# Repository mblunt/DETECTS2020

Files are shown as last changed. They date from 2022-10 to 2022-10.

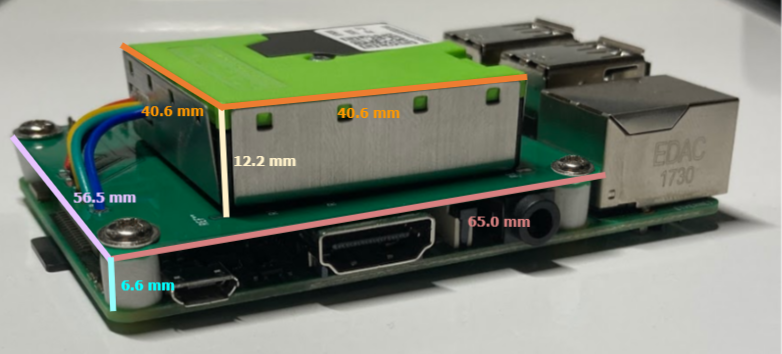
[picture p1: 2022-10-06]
Pictures/Experiment.PNG

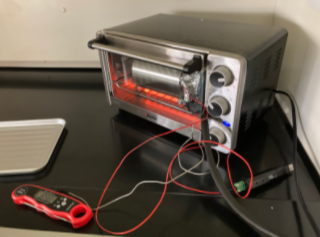
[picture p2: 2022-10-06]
Pictures/HeatTest.PNG

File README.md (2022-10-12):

# Experiment Test Report
### Update
##### Project accepted on AR2B, experiment will be traveling to the International Space Station. For any questions, please contact this experiment's Project Manager, Michael Blunt at michaelbblunt@gmail.com.

### 1.0	Introduction
“Smells Like Particulate Matter” is Palmetto Scholars Academy’s team in the Data Evaluation From Testing via an Educational Challenge with Teachers and Students (DETECTS) initiative with the University of Alabama in Huntsville (UAH). The DETECTS mission will take place in ACES RED 2B (AR2B) on an external pallet attached to the International Space Station (ISS). AR2B’s primary objective is to study quantum entanglement technology in space satellite communications. The primary purpose of DETECTS on AR2B is to investigate the use of low-cost commercial-off-the-shelf (COTS) hardware. The team’s mission is to develop an experiment that utilizes a Raspberry Pi computer in conjunction with sensors to fulfill a scientific objective. The team must select a scientific objective to build an experiment around, program the Pi, and confirm that it meets all functional and environmental requirements through testing. In addition, they must professionally communicate their progress with a panel of evaluators. 
All DETECTS teams were given a detailed Request for Experiment (RFE) and Interface Control Document (ICD) with the requirements that must be met in order to qualify for a slot on AR2B. The experiment would be stored in AR2B, where it would generate and relay data back to the team for evaluation. The project requirements for the team’s experiment is broken down into four categories. The team must follow mechanical and spatial requirements by keeping the experiment no larger than 65 mm by 56.5 mm by 19 mm, and by not modifying the existing Pi mounting configuration or the existing 40W connector pins. Electrical requirements detail that the experiment must be compatible with the existing 40W pinout and that the team cannot use pins 30 or 31. Mechanical aspects of the experiment must be stationary and solid to avoid any damage to the experiment and AR2B. The team cannot include: liquids or gasses of any kind, organic material, loose or powdered material, high voltage equipment (>28V), EMF producing equipment, pressurized vessels, moving parts, reconfigured pinouts, fracturing or shattering materials, batteries, or electrolytic capacitors. In terms of software, all programs must be able to interface and collect data from a Pi HAT and not exceed a data rate of 5 kilobytes per second (kBps). Also, the team must be able to communicate with the AR2B flight computer via the team’s unique JSON packets passed to UAH’s team sender program through placement in the /tmp/experiment directory.

### 2.0	Science Objective and Instrumentation
The team came up with a total of three potential science objectives, “Material Reflectivity,” “Commercial Grade Contaminants Comparison,” and “Fiber Optic Radioactivity.” Material Reflectivity would measure the reflectivity of specific materials with a reflectance sensor within the near-zero lux environment of the AR2B tray. Many consumer technology devices, such as screens, use reflectivity to function, so specific research on reflectivity can assist in material selection for future spaceflight missions. Commercial Grade Contaminants Comparison would be studying and assessing the particulate matter present on AR2B utilizing a particulate matter sensor. There is a significant price difference between consumer and professional grade particulate sensors, and analyzing a consumer grade sensor will establish whether or not this differential is warranted. Fiber Optic Radioactivity would study the effects of background radiation on fiber optic cabling by utilizing a simple voltage output and input to measure any losses. This is key to figuring out the effects of spatial radiation on connectivity with fiber optics. 
In order to choose a scientific objective to pursue, the team used a science objective trade study (Table 2) with weighted figures of merit (FOMs). The FOMs assigned by UAH were Interest of Team, Measurement Method, Likelihood of Success, Sensor Complexity, Sensor Resolution, and Scientific Ramifications. In addition, the team added three FOMs: Justifiability, Public Interest, and Public Comprehension. All FOMs were given a weight of either 1, 3, or 9. After careful consideration and research, “Commercial Grade Contaminants Comparison” won with a weighted score of 337, due to its high scores in Measurement Method, Likelihood of Success, and Interest of Team. The high score in Measurement Method was due to the highly tested nature and quality of the instrument, and high scores in likelihood of success are due to the stability of the experiment’s design in concept and programming.
“Commercial Grade Contaminants Comparison” will establish an experiment to compare the quality and quantity of data collected by commercial-grade vs professional-grade equipment. In order to do this, the team will assess particulate density, prevalence, size, and levels over time while onboard AR2B in order to proceed with a data comparison analysis. All of this will be done in order to gather data on the difference in both the quality and quantity of measurements between consumer and professional-grade sensor technology. After some research on different types of sensing technology, the team has come to believe that the inaccuracy of data generated by commercial-grade sensing technology will not be impressive enough to warrant the costs typically associated with the more expensive professional equipment. The goal in mind for this experiment is to determine whether or not commercial-grade sensors and COTS (Commercial Off the Shelf) hardware are accurate and reliable enough to be used in future missions. If the data gathered from the prospective experiment provides evidence in support of this claim, COTS equipment may be able to replace or supplement far more expensive sensors that have similar purposes. In order to complete the science objective, the experiment must be able to measure particulate density, prevalence, size, and levels over time. Also, the sensor must be able to take measurements on AR2B. 
After significant research, the team decided on the Sensirion Particulate Sensor 30 (SPS30), a consumer-grade particulate matter sensor (See Science traceability Matrix, Table 1). The SPS30 features a compact design, measuring 40.6 mm x 40.6 mm x 12.2 mm, and can measure particulate matter as small as 0.3 μm, a figure slightly better than the posted value for the ISS’s Analysing Interferometer for Ambient Air (ANITA), which currently serves as the ISS’s air quality monitoring system. The SPS30 also features an impressive accuracy of +/-10 μg/m3, as well as a long term accuracy drift of +/- 1.25 μg/m3 per year and a Pi compatible digital output. The SPS30’s small profile combined with very high accuracy and reliability ultimately made it the best fit for the team’s experiment. Due to the design of the SPS30 and the microgravity conditions the experiment will experience, the experiment will be able to take highly accurate measurements simply by running and has no notable limiting requirements. In Table 2, the team describes the process through which the team used to determine the best sensor for their science objective.
The reason the team chose to research a particulate matter sensor, in particular, is based on research the team has done into the ISS’s current air quality monitoring system, the aforementioned ANITA. It is a system that can measure particulate matter up to the “high parts per billion” or >0.5 μm range, as well as to detect over 32 different types of harmful trace gasses. It was developed in the early 2000s, and presumably cost multiple millions of dollars to produce, engineer, design, and qualify. This team’s experiment includes a $45 sensor that can detect smaller particles (>0.3 μm) with a higher degree of accuracy. This team believes that the current particulate matter sensors used in spaceflight missions may be outdated; in addition, the laser-based measurement technology as seen in sensors like the SPS30 may prove to be better suited for missions than the infrared technology used in older sensors such as the one integrated into ANITA. This team believes that an SPS30 may be able to produce results with comparable or higher accuracy to the existing ANITA system, with the added perk of a price point less than 0.001% of the cost of the existing technology (assuming the particulate sensor in ANITA cost at least 5 million to develop, engineer, and implement). With this stated, the team is by no means questioning the accuracy or engineering of the ANITA, as sensing particulate matter is just one of many functions it performs. The above explanation of the ANITA is by no means all-encompassing, and a device like SPS30 could never replace such a system by itself; However, validating the accuracy and usability of a COTS device such as the SPS30 aligns very well with the secondary objective of AR2B, could potentially have very important implications in terms of future mission costs, and could also lead to new, more accurate systems being created with these new technologies. 

#### Table 1. Science Traceability Matrix

Table_1

#### Table 2. Science Objective Trade Study

table_2

### 3.0 Configuration
The team’s mission utilizes an SPS30 mounted on a custom Raspberry Pi Hardware Attached on Top (HAT). The HAT is a printed circuit board (PCB) with dimensions of 65 x 56.5 x 0.8 mm. This HAT integrates the selected sensor, the SPS30, by mounting it via screws and a connector for the sensor. This allows for a stable mount throughout the course of the mission. The HAT design also allows for the use of the 5 pin connector standard utilized by the SPS30 for ease of installation and troubleshooting. Additionally, the HAT meets all the requirements for a Pi HAT, such as utilizing all 40 general-purpose input/output (GPIO) pins and following all solder trace placement guidelines. The HAT is mounted utilizing 6mm standoffs, to ensure the most stability when AR2B encounters inclement conditions. As depicted in Figures 1, 2, and 3, the SPS30 will be roughly centered on the Pi HAT and will be connected to the GPIO pins via the traces and solder connection pads integrated into the PCB board.

#### Figure 1. HAT CAD



#### Figure 2. 3D CAD



#### Figure 3. CAD Side View



#### Figure 4. Concept of Operations Flowchart



### 4.0	Concept of Operations
This experiment divides its concept of operations into three phases. Phase 1 is dedicated to powering up and utilizes a cron job to launch all of the required programs. During this phase, the SPS30 also powers on, and the monitor program ensures that all programs launched successfully. During Phase 2, the experiment operates for twelve hours at a time, then stops and restarts for approximately two minutes. This restart period ensures that if any errors are missed by the monitor program during the mission, a minimal amount of data would be lost. Additionally, the monitoring program performs a soft restart (SPS30 power is not cut) if an error occurs. During this phase, the experiment sends data to the AR2B data handling system at a max data rate of 0.5 kilobytes per second. During Phase 3, the experiment sends its last data packet and powers off approximately 14 days before the end date of AR2B. This is to ensure that little data is lost, while also ensuring that the team does not interfere with AR2B’s end of life plans. After the team receives all the data from the experiment, the team will look for any statistically significant data present, and then create a report outlining the findings, and the implications thereof. This team’s concept of operations is depicted visually in Figure 4.

### 5.0	Programming
The team’s mission program consists of five crucial programs: A startup program, a sensor program, a transfer program, a monitor program, and UAH’s program. Figure 5 shows the basic operation of the programs. In Figure 5, the team uses green lines to represent the data cycle of the program, red lines to represent a triggered restart, and the blue lines represent the log cycle. 
The startup program is launched as part of the Pi’s bootup sequence through a feature built into the native Linux-based operating system called a cron job. This cron job runs automatically as part of the Pi bootup sequence and launches the startup program. Then, the startup program initializes and launches all of the programs needed for the mission, as well as starting a twelve-hour restart timer. The startup program is written in Bash due to Bash’s compatibility with the native Linux-based shell. The startup program launches the monitor program two minutes after the Pi’s bootup sequence completes. This allows time for all of the other programs to launch and begin functioning properly. After the two minutes are elapsed, the monitor program checks to make sure that all other programs are running. If a program has terminated or stopped producing data, the monitor program will initiate a soft system restart. The monitor program is written in Python. 
The startup program also launches the sensor program (immediately). The sensor program, written in Python, configures the sensor by writing to the sensor’s control registers and reading data from the sensor’s output registers. This data is collected by the Pi by the I2C protocol and is packaged into a timestamped JSON file no more than sixty times per minute. Because the largest possible data packet is approximately 450 bytes, the maximum data rate of the experiment is 0.5 kBps. The data output from the sensor can delineate by particulate matter diameter (<0.5μg, <1μg, <4μg, <10μg, >10μg) and also calculates particulate matter density in μg/m3. All of this data is very useful for validating the accuracy and reliability of the SPS30. Specifically, this gathered data will be analyzed by the team and compared to predicted results, testing results, prior mission results, and any other data figures relevant to the collected data. Depicted in Figure 6 is a screenshot of a JSON data packet assembled by the sensor program. 
The transfer program is a simple program designed to move the timestamped JSON files to the /tmp/experiment/ directory (folder) as required by the DETECTS ICD. All this program does is make the /tmp/experiment/ directory, as it is intentionally deleted by the system with every reboot, and it moves all JSON files to the /tmp/experiment/ directory to be handled by UAH’s program. The transfer program is written in Bash.
### 6.0 Functional and Environmental Requirements
While onboard AR2B, the experiment will have to remain functional within the environment. As defined by the RFE and ICD, there are certain functional requirements alongside several environmental requirements that must be met in order to qualify as a sub experiment for AR2B.
In order to meet the basic functional requirements laid out by the RFE and ICD, the experiment must be able to take measurements, organize data packets, and send data. This team chose to include several more requirements to better suit the mission and demonstrate the team’s focus on safety and reliability. These additional requirements include establishing an accurate particulate count, handling program errors, and resuming operation after a reboot. The latter two requirements were added in order to take into account unpredictable or unexpected errors that may occur during the mission. 
To be able to meet the environmental requirements, the experiment must survive the conditions that will be experienced while aboard AR2B. These environmental conditions include surviving extreme temperatures (as low as -20℃ and up to 90℃), surviving a vacuum, and surviving up to 4 gs of random vibration. 

#### Figure 5. Program Flowchart



#### Figure 6. Example Data Packet



### 7.0	Testing
In order to meet the functional and environmental requirements required by the team and UAH, the team created a test plan for functional and environmental testing. The tests designed include the functional tests, which includes the Sensor, Transfer, and Recovery, as well as the environmental tests, which include the Vacuum, Thermal, and Vibration tests. For all of these tests, the safety of the team members and the experiment was considered to be the main priority. During testing, team members present wore proper personal protective equipment (PPE), had emergency equipment in the room, cleaned and inspected all equipment before use, and made sure they were operating in a clear and safe lab environment. Steps taken to ensure the safety of the experiment include using grounded wristbands and ground-fault circuit interrupter (GFCI) equipped outlets. In addition to the listed precautions, additional measures were taken for certain tests due to a unique situation posed by the test or testing environment.
The first functional test, the Sensor test, was created to determine if the experiment can take measurements, organize data packets, send data, and establish an accurate particulate count. For the experiment to pass this test, it must accurately reflect an increase in particles when a particulate source is introduced. For this test, the experiment was placed in an enclosed container and was run for one hour to establish a baseline measurement. Then, a lit butane lighter was inserted into the container for 5 seconds. Following this, the testers removed the lighter and resealed the container. The test was successful as the experiment worked as expected, showing a 17,600% increase in particulates (μg/m3). 
The Transfer Test was the team’s second functional test, and it was made to determine if the experiment can organize data packets and send data. To pass this test, the experiment must accurately transfer JSON data packets from the /tmp/experiment/ directory to the UAH transfer program. This test was completed by simply powering on the experiment, and ensuring that the UAH program was receiving the packets via the program’s built-in data rate feature. The transfer program was successful in transferring the time-stamped files to the /tmp/experiment/ directory, and per the UAH transfer program, the experiment has a current maximum data rate of 0.5 kBps and an average of 0.3kBps. This test was run 25 times with zero failures.
The final functional test was the Recovery Test, which determined if the experiment can handle program errors and resume operation after a reboot. To pass this test, the experiment must be able to restart after SPS30 power loss, disconnected GPIO wires, and halted programs. The test was run 50 times with the experiment rebooting successfully every time. 
The Thermal Tests, namely the cold and heat test, were completed in order to meet the requirements of surviving within the temperature extremes of -20℃ and 90℃. To pass these tests, the experiment had to be able to function and take measurements while experiencing temperatures up to 90℃ and as low as -20℃. This test was completed using a freezer cooled to -20℃ (pictured Figure 7) and a toaster oven provided by UAH (pictured Figure 8), which was heated to 90℃. First, each individual component of the experiment, the PCB, SPS30, and wires, were each tested at 90℃ for an hour and -20℃ for an hour. After testing the individual parts of the experiment, the fully assembled configuration was operated at 90℃ for one hour and -20℃ for one hour. During each environmental condition, a variation of the sensor test was completed to demonstrate the experiment’s ability to function at different temperatures. This variant of the sensor test was completed by inserting the experiment into a particulate containing canister. During the cold test, this variant of the sensor test was completed for 10 minutes in the middle of the cold test, creating a 0-25 minute cold test and a 35-60 minute cold test. The experiment worked as expected and the sensor was able to function successfully in both environments.
 The vacuum test was made to determine if the experiment could survive, take measurements, organize data packets, and send data in vacuum-like conditions. To pass the vacuum test, the experiment was required to be able to survive (UAH requirement) and operate (Team Requirement) within a vacuum for 30 minutes. Prior to testing, a vacuum chamber provided by UAH was cleaned, re-oiled, and inspected for defects. After this, the experiment was run inside the vacuum chamber for 30 minutes (pictured Figure 9). While re-pressurizing the chamber, we introduced particulates to further demonstrate the experiment’s ability to function in a vacuum. The experiment was able to survive and detect particulates while operating within a vacuum for 30 minutes and met all requirements set by the team and UAH; therefore, the experiment passed the vacuum test. 

#### Figure 7. Cold Testing Setup



#### Figure 8. Heat Testing Setup



#### Figure 9. Vacuum Test Setup



The random vibration test was designed to determine if the experiment could maintain structural integrity while experiencing up to 4g of random vibration (max g-forces shown in Table 3). The purpose of this test is to simulate rocket launch. To pass this test, the experiment must remain intact and operable after surviving these conditions. For this test, the payload and a UAH provided accelerometer was secured to a baseplate (experiment depicted in Figure 10) and vibrations were introduced for 15 minutes according to UAH recommended testing guidelines. Specifically, the experiment and accelerometer were mounted to a wooden board and placed on an egg crate foam dampener. Then, the board was hit at different angles with a rubber mallet into the egg crate foam dampener to generate the necessary g load without putting undue stress on the experiment. After testing, the experiment was inspected for any hanging or disheveled parts and the data collected afterwards was compared to the data collected prior to testing to determine success or failure. Ultimately, the experiment passed the vibration test as the experiment was able to survive and function accurately after the vibration test.

#### Figure 10. Securely Mounted Pi



#### Table 3. Calculated G-Forces on Pi

table_3

### 8.0	Data Analysis
 The team was careful to take a sequential and organized approach to gathering and analyzing data. After a test was conducted, all data packets gathered during the test were transferred to an analysis computer via a remote connection. Once the data was successfully transferred to the analysis computer, a Python program designed to extract relevant data was run on the collected data packets. Once the necessary data had been extracted, the data points were imported into a labeled spreadsheet. Once in the spreadsheet, that data was analyzed using a variety of statistical tools, formulas, and graphs. The team conducted many types of regression, created control charts, estimated confidence intervals, f-tests, and many other types of analyses. 
 As suggested by UAH presentation guidelines, the team conducted a statistical analysis on data collected during the functional tests. For the recovery and transfer test, no new information could be gathered by analyzing the particulate data collected, as the manipulated variable for those tests was independent of all variables affecting the reliability of the SPS30 itself. For the Recovery test, no notable data could be gathered except that the triggered error to shutdown delay time is less than one second, and the reboot time is a maximum of 120 seconds. For the transfer test, the largest possible data packet was approximately 0.47 kilobytes, and at a set maximum rate of 1 data packet per second, the maximum possible data rate is 0.47 kBps based on the data from the transfer test. To determine the average data rate, the total size of 600 data packets was divided by the total time taken to transfer the packets, resulting in an average data rate of 0.312 kBps. For the sensor test, a baseline sample was taken for 1 hour. As the baseline particulate count was so small compared to the values collected after particulates were introduced (a ratio of 1:178), there was no need to conduct an analysis to see if there was a difference in particulates between the baseline and testing data. As opposed to the limited analysis conducted for the functional tests, the team decided to conduct a much deeper analysis of the data gathered during environmental tests that was required by UAH.
 For the environmental tests (vacuum, thermal, and vibration tests) UAH only required a basic analysis of the data collected. The suggested method for data analysis was to visually compare collected data to a baseline. This team decided to conduct deeper analysis to validate the functionality of our sensor in addition to comparing data to a baseline as recommended by UAH. For the thermal (heat and cold) tests as well as the vacuum tests, the same statistical process was used to analyze the data. This process was (in essence) to take the derivative of the particulate data and create a linear regression (a linear line of best fit) from this data. The purpose of taking the derivative of all of the particulate data was to determine if the rate of change of the data over time was increasing, decreasing, or remaining constant. 
When the graph of the thermal (heat and cold) tests were analyzed, the team discovered that the slope of the linear regression of the data was slightly negative for both tests (shown in Figure 12), indicating that the total number of particles had decreased during the test. However, this decrease was so small, that, when applied back to the original data set, it resulted in a decrease of approximately 6.733 ng/m3 (heat test) and 17.823 ng/m3 (cold test 0-25) and 12.909 ng/m3 (cold test 35-60). After determining this, the team realized that the decrease was so small that it could be considered an insignificant data point. Furthermore, the environment could not be fully controlled, due to the location of the heat test in a fume hood and unsealed oven, and the cold test in a partially sealed container and a standard freezer. As such, slight inconsistencies are to be expected and, due to the nature of the experiment, are irrelevant to the team’s objective. 
When the data from the vacuum test was analyzed, the team discovered that the slope of the linear regression of the data was exactly zero (shown in Figure 11). Using this statistical evidence, the team concluded that regardless of fluctuations, the amount of particulates within the vacuum chamber remained constant. This data supports the hypothesis of the team, who inferred that because the vacuum chamber is a sealed container with no particulate sources, the particulates count within the container will remain constant. This statistical analysis, in addition to the baseline, effectively demonstrated the experiments ability to survive, collect data, send data, and function accurately within a vacuum.

#### Figure 11. Vacuum Test Data Analysis



#### Figure 12. Heat Test Data Analysis



Finally for the vibration test, no particulate data was collected, as the experiment will not be operating in an environment that this test attempts to simulate, namely, the rocket launch. However, before and immediately after the vibration test (Figures 13 and 14), the experiment was powered on to verify that the sensor and all connections were working properly and establish baselines. From both baselines, 600 data packets were gathered and compared. Both baselines had their upper limits within ± 0.05 μg/m3 of each other, a lower limit within ± 0.1 μg/m3 of each other, and a mean of approximately 2.25 micrograms per cubic meter for both. In conclusion, all functional and environmental tests demonstrated that the experiment was able to meet all requirements set forth by the team and UAH, and generated accurate data packets in all environments and after all tests. 

#### Figure 13. Baseline Before Vibration Test



#### Figure 14. Baseline After Vibration Test



### 9.0	Online Outreach Platform
The team’s choice of social media platform for outreach was Youtube. Due to its unique characteristics as a platform, the team was able to present its STEM-focused platform in the most dynamic way possible. In contrast to posting in a photo-and-caption format, using a video-based platform allowed the team to be creative and have a multitude of topics for video content. Based on a certain week’s video topic, the team was able to post either discussion style, activity, or “vlog” type content to engage audiences as much as possible. To complete their video-centered content plan, the team decided to utilize Youtube as their platform, as it is one of the leading online video hosting websites. 
	The DETECTS program outlines requirements and guidelines for creating specific content to be completed by individual teams. The team began video content with a trailer, targeted towards middle school and high school audiences. The trailer was created as a parody of a very popular television show called “The Office.” This parody was intended to be the first video viewers saw when visiting the channel page, in order to set a fun and unique tone that showcases the engaging and interactive dynamics for the entire channel. After the parody introduction video, the team began creating video content showcasing DETECTS specific content and our science or experiment objective. These videos were posted as a continuation of the team’s introduction video to cover the basics of who is on the team, what the team is doing, and the purpose for the channel. These videos were shortly followed by the team’s outreach specific videos. The team’s outreach videos cover the basics of outreach and further explain the team’s specific goals for the channel and were started by the first two activity video posts. The first activity video showcased a model solar system built by the team. This video was meant to create engagement for younger audiences and highlight the teams’ experiment’s hopeful destination, space. The following video covered the DETECTS competition and basic information covering the AR2B mission. The next three videos posted to the channel covered the objective, the experiment, and an introduction to the testing process. The team had then reached a point in the competition where they began the testing process and a bulk of the live footage, featuring a series of videos titled the Testing Saga. The first video in the saga covered the materials unboxing, the second the team’s Functional and Vacuum Testing, the third being the thermal testing, and finally the fourth being the team’s vibration testing. The team posted our Data Analysis video after the Testing Saga as a closing to the testing phase and allowing the viewers to get a look at the experiment’s testing results and physical data. Our final additions to our channel were the project summary video, where the team covered the final project, the pros and cons video where they discussed what they learned from their time competing in DETECTS, and our preparation for our final presentation video where we took our viewers through the process of completing the final steps of the project. Our team’s last upload was a thank-you video where each team member thanked the channel’s viewers and discussed what will happen next.

#### Figure 15: The Team’s Youtube Channel



The team’s main objective with Outreach over the course of the competition was to introduce and engage students into the world of STEM. The team wanted their channel to serve as inspiration to its viewers, and encourage them to seek out opportunities through their own schools or communities. The team also assigned themselves the goal of hopefully giving their viewers something to take away from the videos in terms of what it means to work on a team, applying what they learn in their classrooms to real-world simulating activities and competitions in a fun manner. 
	The team performed two activities on their outreach platform. The first was our building-a-model-solar-system activity. Due to the team’s science objective being very specific, particulate matter, they wanted to find a broader but still relevant topic to base their activity around. They chose to find something to do with the destination of their experiment. A model solar system allowed the viewers to draw a connection between what the team is working on now with the experiment and the scale of the end goal. This activity was able to demonstrate the place the ISS calls home, our solar system, in a way that also included fun facts surrounding all eight planets. The second activity was in the form of a demonstration. In one of the testing videos, we performed our vacuum tests. Since the experiment is solid, there wasn’t much of a visual reaction when it was placed in a vacuum, and therefore it was harder for the younger viewers to understand what a vacuum is. The team performed different tests using miscellaneous objects from their school and filmed what happened to the objects as they were put into and then taken out of a vacuum. This demonstration had the purpose of developing a better understanding of not only the testing process but also the climate of the solar system, where the experiment may eventually end up on the ISS.

### 10.0	 Project Summary
During the first half of this project, “Smells Like Particulate Matter'' established as a team and selected three potential science objectives, “Material Reflectivity,” “Commercial Grade Contaminants Comparison,” and “Fiber Optic Radioactivity.” After conducting a trade study, the objective “Commercial Grade Contaminants Comparison” was selected due to its high scoring in team interest, measurement method, and the likelihood of a successful experiment. After choosing this science objective, the Sensirion SPS30 sensor was chosen, a custom Raspberry Pi HAT was modeled, and the experiment was programmed to ensure proper functionality. Additionally, “Smells Like Particulate Matter” conducted functional tests in the first semester to ensure functionality of the Raspberry Pi HAT configuration and the program structure. Going into the second (testing-focused) semester, the team developed plans to ensure that the configuration would be tested up to the requirements specified by UAH and the team. 
As shown in Table 4, The experiment meets all ICD requirements. “Smells Like Particulate Matter” was tasked with ensuring that the experiment configuration would properly function in all conditions. To ensure all environmental variables were accounted for, the experiment withstood thermal, vibration, and vacuum tests designed to determine its limits. Some of the equipment used in these tests include a toaster oven, a vacuum chamber, a freezer, a vibrating baseplate, and an assortment of sensing equipment. The experiment passed all of these tests with no error, leading the team to conclude that, based on the requirements, the configuration is up to UAH standards. Overall, it is the opinion of this team that the experiment could validate an important piece of equipment through its proposed evaluation in spaceflight. In addition, the validation of the SPS30 would help facilitate the integration of cost effective replacements for existing equipment on platforms such as the International Space Station and its ANITA air quality monitoring system.

Table  4: ICD Compliance Table

table_4

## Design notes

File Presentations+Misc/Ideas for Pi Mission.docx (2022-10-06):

Space is an absolute vacuum, what can we measure from this?

General Measurement Topics:

- Earth’s atmosphere
- Infrared Space Stuff
- Signals sent off Earth

Could make a map of the Earth out of Radio Emissions

- Energized Particles and Solar Storms
- The effects of microgravity on protein crystallization: evidence for concentration gradients around growing crystals
  - https://www.sciencedirect.com/science/article/pii/S0022024898008537
- Effectiveness/Degradation of Lubricants in Space
  - Under radiation in a microgravity environment
- Fiber-Optic Cables in Space
  - No gravitational pull, photons have no dropoff, faster speeds?
  - Fiber might break, loss of photons
- Magnetic Fields Impacting Electrical Conductors
  - High accuracy sensors surrounding an electrical conductor, earth’s magnetic field affects conduction?
  - Might impact other experiments, shielding?
- Degradation of Solids in Space
  - With virtually zero-g (and radiation), some solids may start to break apart or deteriorate. The rate could be useful for future space materials.
  - Our first ideas involved the study of materials such as plastics and microwires
  - Our secondary ideas include the study of the degradation of certain pharmaceuticals and their potency in space.
    - How to measure potency?

See what kinds of energized particles are affecting the ISS

Cosmic Background Radiation

Remnants of Gamma Ray Bursts (Not likely but maybe)

Compare data with other observation tools to see if ratios match, as the signals will be dimmer inside of the capsule

Potential Secondary Missions:

- Recording Sounds on ISS, e.g. space noises

New Ideas:

- Osmosis
- Cement
  - On earth, when cement forms, the denser materials settle to the bottom of the mixture.
  - In a microgravity condition, the denser materials should be distributed uniformly, creating a stronger material
- Insulin
  - How the potency/chemical structure of insulin is affected by any radiation from space and/or the ISS
- Structural Integrity of 3d printed plastics (And maybe microplastics)
  - Degradation of additive materials in microgravity conditions
- Tin whiskers?
  - Under extreme gravity conditions, wires produce thin whiskerlike metal strips
- Protein Crystallization
- Oscillation of the station through normal everyday activities.
- Wear and tear of different electronic devices in microgravity
- Time dialation between surface of earth and ISS
- Degredation of adhesive strength in microgravity

Even More Ideas

- Capillary Transport Systems
  - Certain materials, such as plants are capable of transporting nutrients and fluids against gravity via capillary tissues such as xylem and phloem,

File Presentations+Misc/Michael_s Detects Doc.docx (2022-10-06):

Experiment Config Instructions

This guide will go over exactly how the pi was assembled.

Materials:

- 1x Custom Designed PCB board
- 1x Shortened Connecter Configuration
- 1x SPS30
- 1x PI 3B+ (not needed for soldering)

Tools:

- Soldering Iron
- Clamps (something to hold parts steady while soldering)
- Solder
- Soldering Iron Stand
- Wet Sponge (clean soldering iron)
- Multimeter
- Table protector

Recommended Safety Equipment

- Fire Extinguisher
- N95 Mask
- Protective Gloves
- Fume Hood
- Safety Glasses/Goggles
- Lab Coat (protect clothing)

Testing Schedule

Heat Test - 2/10/21

Chill Test - 2/17/21

Rumble Test - 2/24/21

Vacuum Test - 3/04/21

Testing Instructions:

HEAT TEST

Equipment Phase:

1. Put on flame-resistant lab coats, safety goggles, heat resistant gloves/mitts, and N95 masks.
2. Remove any jewelry
3. If any tester has hair longer than 5 inches or hair that may cause a hazard, instruct the tester to put their hair up and out of the way.
4. Verify testers are dressed appropriately for the given test, including having closed-toed shoes.
5. Verify that all testers handling the Pi are electrically neutral, ie: do not pose a threat due to electrostatic discharge (ESD)
  a. ESD mats, wristbands, and bonding cables all work to meet this step.
6. Make sure that the proper safety equipment is nearby and working properly
  a. Fume hood (highly recommended)
  b. Fire extinguisher (highly recommended)
  c. Backup Personal Protective Equipment (PPE) (recommended)
  d. First Aid Kit (recommended)
  e. This is not an all encompassing list, it is the responsibility of the testing team to determine what is necessary to ensure the safety of the experiment and the testers.

Preparation Phase

1. Place Oven in fume hood
2. Turn the oven to broil (max temperature) for 20 minutes
  a. (to remove residue from manufacturing process)
3. IMMEDIATELY after turning the oven to broil, close the fume hood completely and turn on the fume hood
  a. Ensure proper ventilation of the fume hood.

Use fume hood, oven may smoke

Testing Phase

1. Seperate each part of the payload, the PCB board, the sps30, the pi and the connector wires for individual testing.
2. Set the Toaster oven to 95 degrees Celsius, allowing the temperature to stabilize.
3. Place one part in the oven for an hour.
4. Repeat the process with each part and then let cool.
5. Check for any damage and report any concerns.
6. Assemble into payload configuration, repeat testing while fully operational.

Chill Test:

Prior to testing, the freezer should be set to -20℃ if possible. The payload will be put into an air-tight container and then put into a freezer with a thermocouple overnight. Once removed from the freezer the payload will be run and the data will be compared to data collected at room temperature. Afterwards the payload will be set until it reaches room temperature before further testing can occur.

Rumble test:

The raspberry pi will be checked for any loose or hanging wires prior to testing ( a snapshot/photo would be great here), after the initial check the payload will be strapped into the accelerometer which will run for 3 hours straight. A photo after the accelerometer is run would be great, and the payload will be checked for any stray, disheveled or broken parts. If nothing has moved, run the payload inside the accelerometer and compare the data with data collected in a normal environment.

Vacuum Test:

The vacuum chamber will be cleaned and inspected for cracks and any abnormalities prior to testing. Afterwards the payload will be strapped and put in a secure location within the vacuum chamber. The payload will be subjected to vacuum-like conditions and ran for 2 hours. After the 2 hours, the payload will be taken out of the vacuum chamber and data collected during testing will be compared to data collected in a normal environment.

Miscellaneous Stuff

When I first began programming, I needed a way to interface with my sensor to test my programming. To do this, I purchased female to female GPIO pin connectors similar to these → link (https://www.google.com/url?psig=AOvVaw2214pADVE8ZYDmcZ5CwFCB&cd=vfe). I also purchased the 5 pin connector for the SPS30, but unfortunately it was a 5 pin connector to 5 pin connector cable, so I had to make some modifications. I cut both wires in half, and striped about a half-inch of insulation off of the wire. I then soldered the wires together and tested the connection with a multimeter.

This wire configuration was used before our PCB board was printed. The soldered wire configuration was simply used for initial programming and troubleshooting, NOT for testing purposes.

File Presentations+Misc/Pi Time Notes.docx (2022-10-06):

Slide 6:

These our our potential science objectives:

Our first potential science objective is Fiber optic Cables in Space:

This potential science objective will measure the speed and efficiency of fiber optic cables in micro and macro gravity conditions.

We will be testing both standard and space grade Fiber-Optic cables.

This objective would serve to measure the effect of gravity on photons and provide data on the performance of an important material.

Our third potential science objective is the Degradation of Pharmaceuticals in Space:

This experiment will measure the potency drop-off and shelf life of common pharmaceuticals in microgravity.

We will collect data using a Chemical Potency Tester.

This is important because it will provide important safety information relating to medicines in space.

Slide 8:

Our Chosen science objective is Fiber-Optic Cables in Space:

As previously stated, we will measure the speed and effectiveness of fiber-optic cables in micro and macro gravity conditions

A fiber optic cable works when a laser injects a beam of light into a core of glass filament, and light bends insid e the cable until it reaches the end of the wire.

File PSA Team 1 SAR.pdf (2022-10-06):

# System Acceptance Review

## Smells Like Particulate Matter Palmetto Scholars Academy Team 1

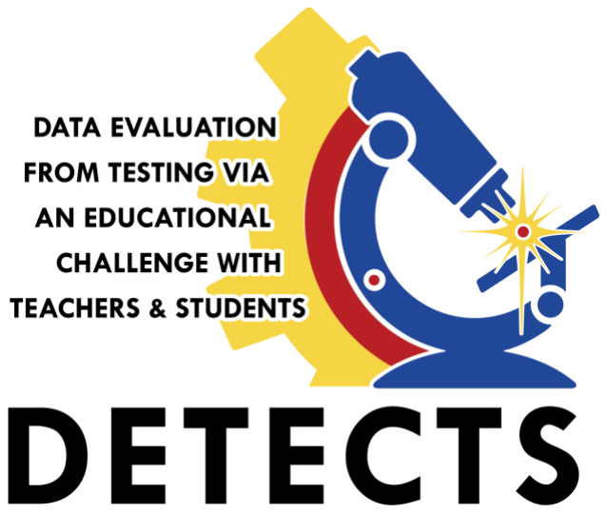
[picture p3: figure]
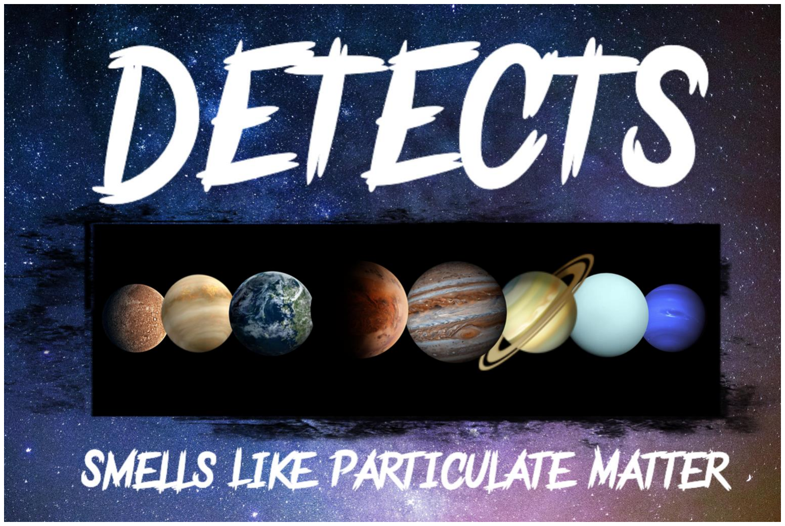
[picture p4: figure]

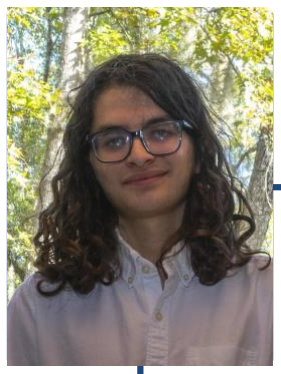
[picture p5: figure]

Test Lead
Emann
Rivero
12th Grade

Chief Engineer
Samantha
Quartuccio
12th Grade

Experiment Lead
Max
Freedman
11th Grade

Experiment Group
Benjamin
Deaton
11th Grade

Team Lead
Michael
Blunt
11th Grade

Test Group/Outreach
Morgan
Peterson
11th Grade

# Smells Like Particulate Matter

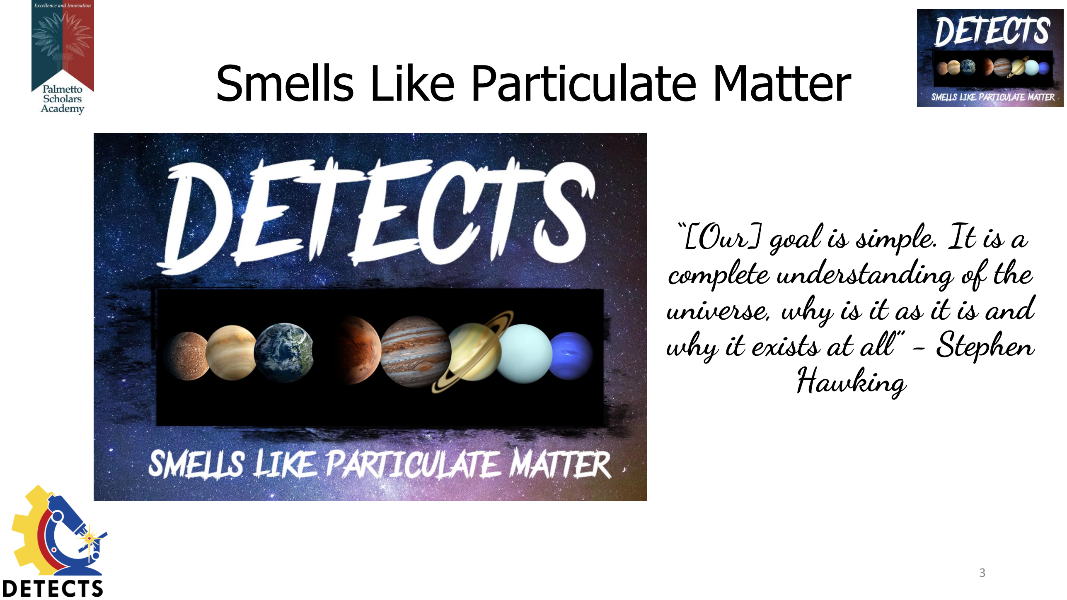
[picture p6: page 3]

# “[Our] goal is simple. It is a complete understanding of the universe, why is it as it is and why it exists at all” - Stephen Hawking

# ACES RED 2B

## - Studying quantum entanglement for space satellite

communications.

## oSponsored by U.S. Space and Missile Defense Command (SMDC)

## - Secondarily investigating the use of low-cost

## commercial-off-the-shelf (COTS) hardware

## oTo replace currently used expensive equipment oPrimary objective of DETECTS

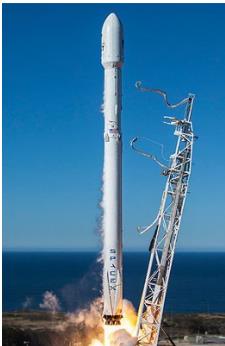
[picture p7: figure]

https://space.skyrocket.de/doc_lau/falcon-9.htm

# Design Requirements

Mechanical/Spatial Requirements | Electrical Requirements
- Must be no larger than 65 x 56.5 x 19mm ● Must be less than 19mm above the surface of the Pi when plugged in | ● NO High-voltage-inducing instruments (over 28 V) ● Pinout used must be the one found on the Pi ● Pins 30 and 31 cannot be used
Material Requirements | Software Requirements
- NO Mechanisms or moving parts
- NO Liquids, gases, or fluids of any kind
- NO Organic material or any other exotic material
- NO Vibrating/oscillating components
- NO Loose/powdered material
- NO Batteries or electrolytic capacitors
- Must be developed on a Raspberry Pi 3B+
- Must operate the Pi HAT and gather data from it
- Data rate must NOT exceed 5 kilobytes per second
- Must communicate with the AR2B flight computer via JSON formatted packets
- Transfer JSON packets into a folder called /tmp/experiment/ in the Raspberry Pi’s file system
- Must include an identifier within the JSON packet

# Experiment

School
Logo Here
Team Chosen Science Objective | Logo Here

## - Science Objective

## oEstablish an experiment that can compare the quality and quantity of data gathered by commercial-grade and

professional-grade particulate matter sensors.

## oAssess particulate density, prevalence, size, and levels over

time in ACES RED 2B using consumer-grade sensors.

School
Logo Here
Team Hypothesis | Logo Here

## - Research Question oWhat is the difference in both quality and quantity of measurement between consumer and professional-grade sensing technology?

## - Hypothesis

## oLaser based consumer-grade particulate matter sensors are more accurate

than existing professional-grade infrared particulate matter sensors.

## - Research

## oANITA, developed in the early 2000s for ISS

## - > 0.7 μm (high parts per billion) - Infrared

## - > 0.3 μm (low parts per billion) - Laser

School
Logo Here
Team Sensor - SPS30 | Logo Here

## The SPS30 particulate sensor is a very small and

accurate consumer grade sensor.
- dimensions: | 40.6mm * 40.6mm *
12.2mm
- min detectable: | 0.3μm diameter
- output: | digital (I²C)
- accuracy: | ±10 μm/m³
- long-term drift: | ±1.25 (μm/m³ )/year

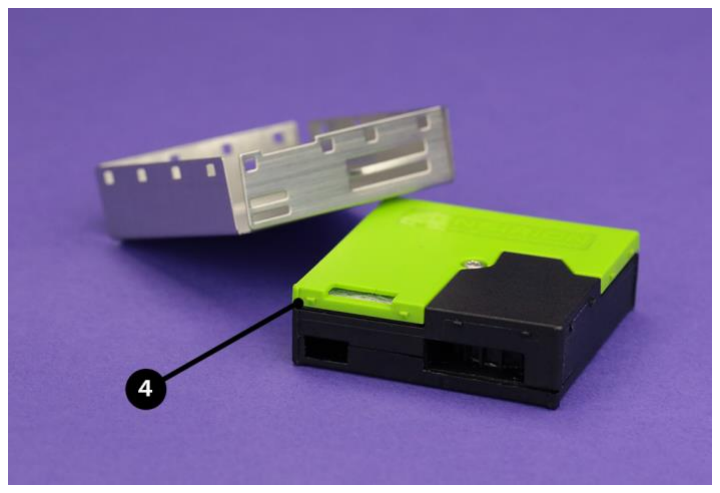
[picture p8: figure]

- laser/infrared: | laser

Team Experiment Design | Logo Here

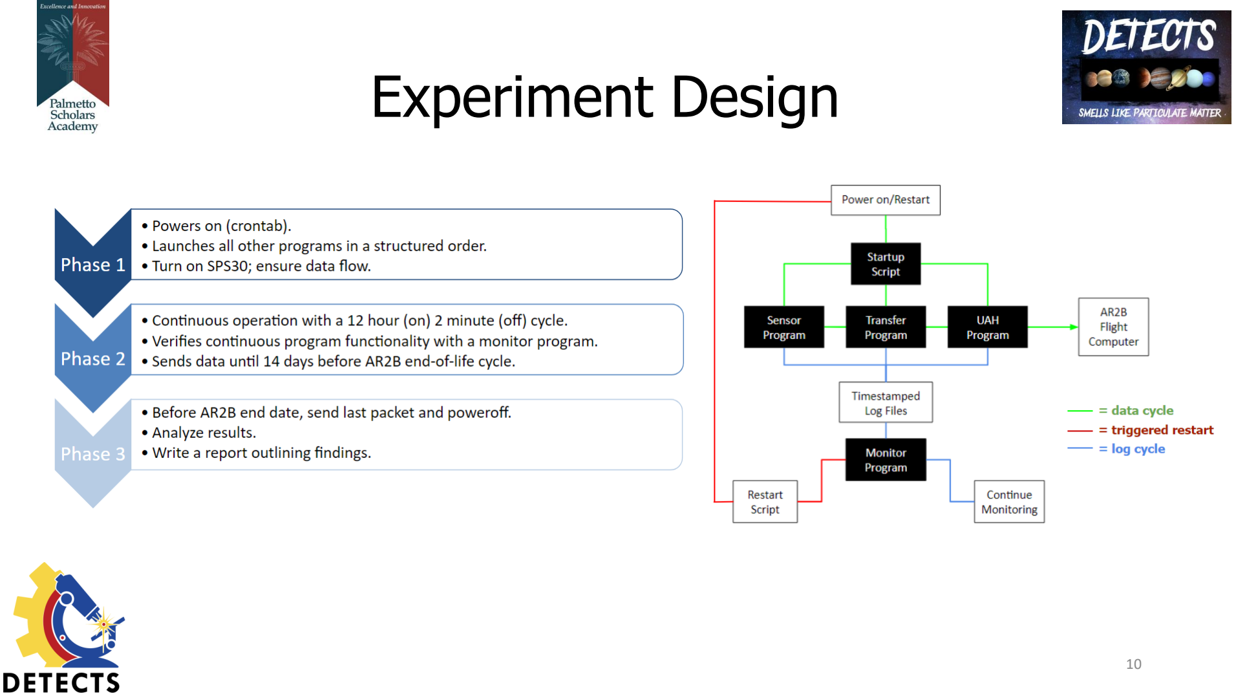
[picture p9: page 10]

School
Logo Here

Team Experiment Configuration | Logo Here (cont.)

School
Logo Here

Onboard NIC
For Reference

GPIO Header for reference

SPS30 - Yellow

HAT Design (CAD)

Through-Hole

65mm

56.5mm

40.6mm

40.6mm

USB Ports for
reference

USB Ports for
reference

Ethernet Port
for reference

SPS30 Mounting Holes

Team Experiment Configuration | Logo Here (cont.)

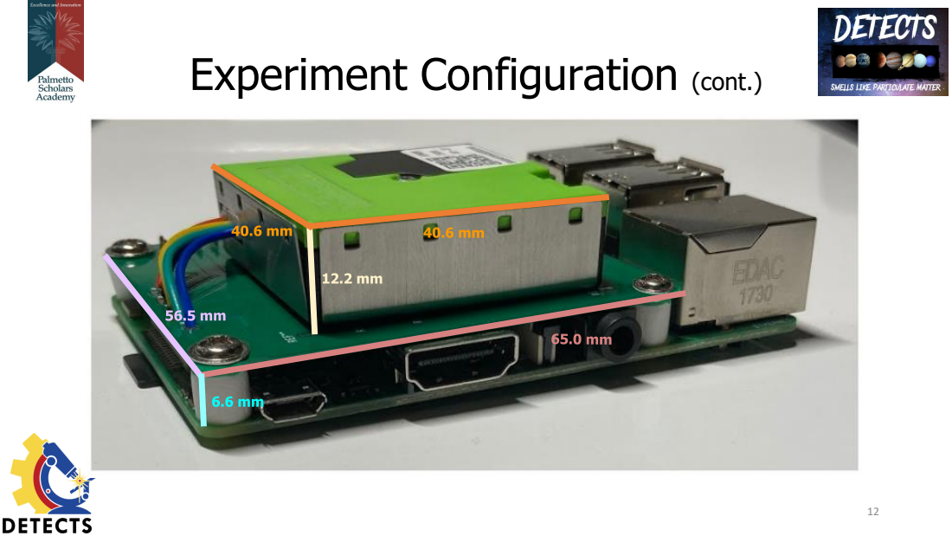
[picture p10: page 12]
School Logo Here

# Testing

# Testable Requirements

Functional
Requirements

Take Measurements

Organize Data Packets

Send Data

Establish Accurate
Particulate Count

Handle Program Errors

Resume Operation After
Reboot

Environmental
Requirements

Survive Hot Environment

Survive Cold Environment

Survive Extreme Pressures

Survive Random Vibrations

School
Logo Here

Team
Logo Here

## General Safety Practices

- Use proper Personal Protective Equipment (PPE).
- Have proper emergency equipment available.
- Ensure proper electrostatic discharge (ESD) protection.
- Use ground-fault circuit interrupter equipped (GFCI) outlets.
- Maintain clear and safe lab environment.
- Clean all equipment before and after use.

## Hazard Avoidance

- Use N95-mask and fume hood to avoid possible inhalation of fumes.
- Verify equipment works before testing. (fume hood)
- Verify integrity and oil level of vacuum pump before and after use.
- Additional examples of hazard avoidance will be listed under the respective tests.

# Safety Plan

School
Logo Here

# Team Functional Test - Recovery Test Logo Here

Test Environment and Reasoning
- Demonstrate that program can handle errors and resume operation at reboot.
- Errors tested: Unplugging SPS30 GPIO data wires, cycling power, killing programs, restarts, shutdowns
- All program-triggered restarts are called by a monitor program

Results
- All programs worked as expected, experiment always started back up after reboot.
■ The monitor program was able to detect and recover from all conceived errors. ■ Test completed 50 times, 0 failures.

Evidence
- A picture of the
populated
/tmp/experiment
directory after a

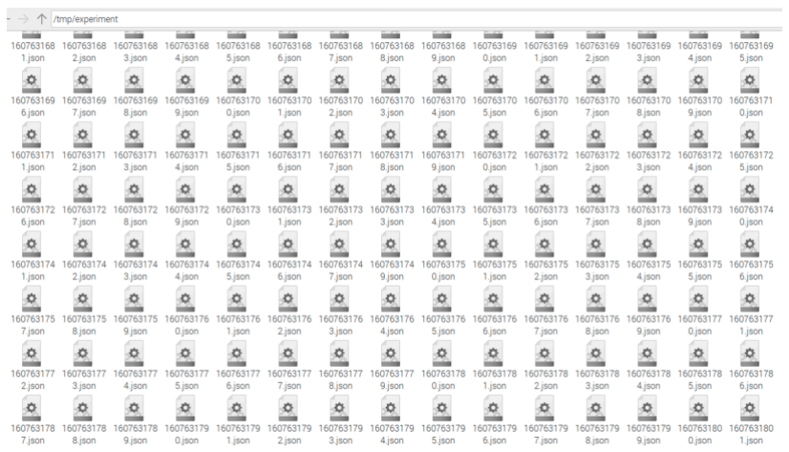
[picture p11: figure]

run with the UAH
program
disabled.

Requirements
- UAH Requirements:
- Take measurements, organize data packets, and send data.
- Team Requirements:
- Handle program errors.
- Resume operation after reboot.

# Functional Test - Transfer Test

Test Environment and Reasoning
- Demonstrates that program can organize and send data packets.
- Used UAH and team transfer programs.
- Verify data collected is organized and transferred to UAH’s data handling program.
- Test completed 25 times, 0 failures.
- Pi was rebooted via various stimuli (see Recovery test).

Results
- The programs all worked as expected, data was transferred in time stamped files to /tmp/experiment/ directory.
■ Max of 0.5 kBps, average of ~0.3 kBps ■ Example from UAH transfer program:

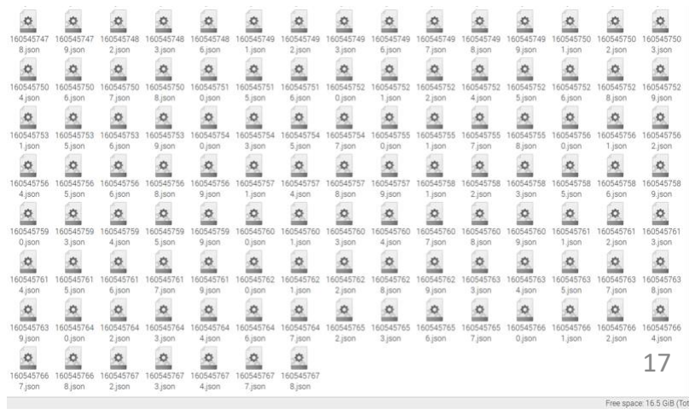
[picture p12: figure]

- A picture of the
populated
/tmp/experiment/
folder after a run
with the UAH
program disabled.

Evidence

Requirements
- UAH Requirements:
- Take measurements, organize data packets, and send data.
- Data rate of less than 5.0 kBps.
- Communicate with AR2B flight computer via /tmp/experiment/.

Test Environment and Reasoning
- Verify sensor is accurate and functional.
- Connected directly to GPIO header.
- Verify sensor can establish accurate particle counts.
- Experiment placed in enclosed container and was run for 1 hour to establish baseline.
- Butane lighter put in container for 5 seconds.
- Lighter removed and container resealed.

Results
- The programs all worked as expected, data was collected with no errors.
■ No errors with I²C connection.
■ Sensor detected particulates accurately. ■ Everything functioned as expected.

Evidence

# Functional Test - Sensor Test

Requirements
- UAH Requirements:
- Take measurements, organize data packets, and send data.
- Team Requirements:
- Establish accurate particulate count.
Baseline Example Packet | Packet After Particulates Introduced

Personal Protective Equipment
- Clothing:
- Lab Coat
- Insulated Gloves
- Safety Goggles
- Equipment:
- Fire Extinguisher
- GFCI protected outlet
- ESD wristband (while handling pi)

Testing Environment/Plan
- Change oil and inspect vacuum chamber for defects
- Test each part of experiment (wires, board, SPS30) individually for 1 hour.
- Follow steps in vacuum testing handout.
- Test assembled experiment with battery for 30 minutes.
- Allow repressurization of chamber, and remove experiment.

# Vacuum Testing

Requirements to Meet
- UAH Requirements:
- Survive vacuum.
- Take measurements, organize data packets, and send data.
- Team Requirements:
- Survive vacuum for 30 minutes.
- Meet all functional requirements.

Results
- Wires | = | Completed
- Board | = | Completed
- SPS30 | = | Completed
- Full Configuration | = | Completed
- More Details:
- Sensor survived vacuum.
- Sensor detects particles in vacuum.
- | Detected additional particles at intake. | 19

# Vacuum Test - Evidence/Results

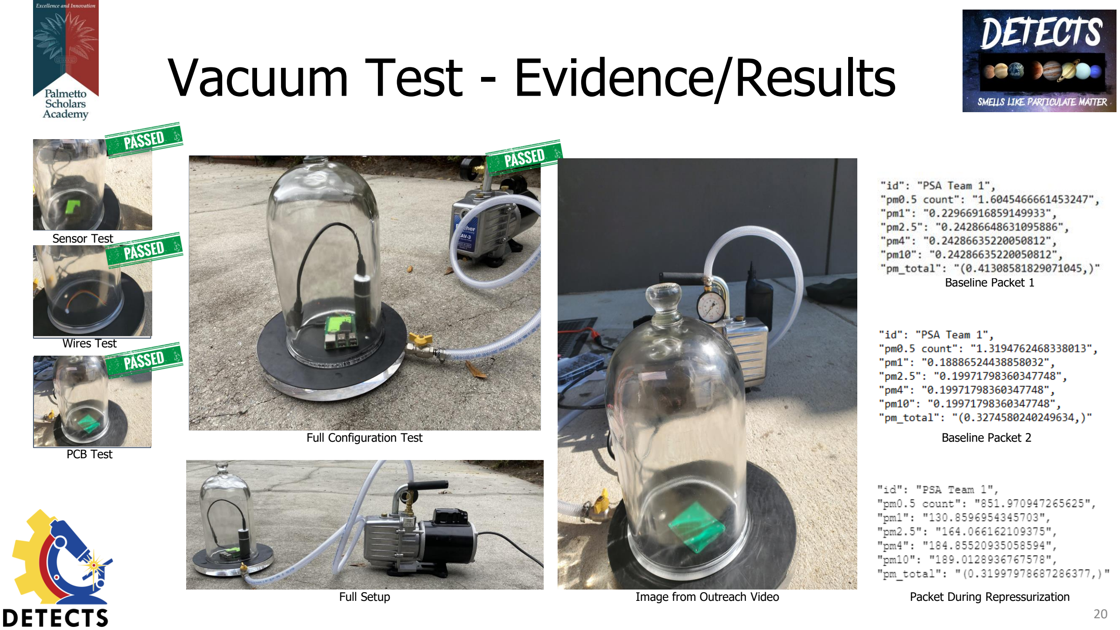
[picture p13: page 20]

Config in Vacuum Chamber

Full setup with
pump in frame

sensor in vac
chamber

Wires in vac
chamber

Board in vac
chamber

Full Setup

Full Configuration Test

Sensor Test

Wires Test

PCB Test

Image from Outreach Video | Packet During Repressurization

Baseline Packet 2

Baseline Packet 1

# Vacuum Test - Data Analysis

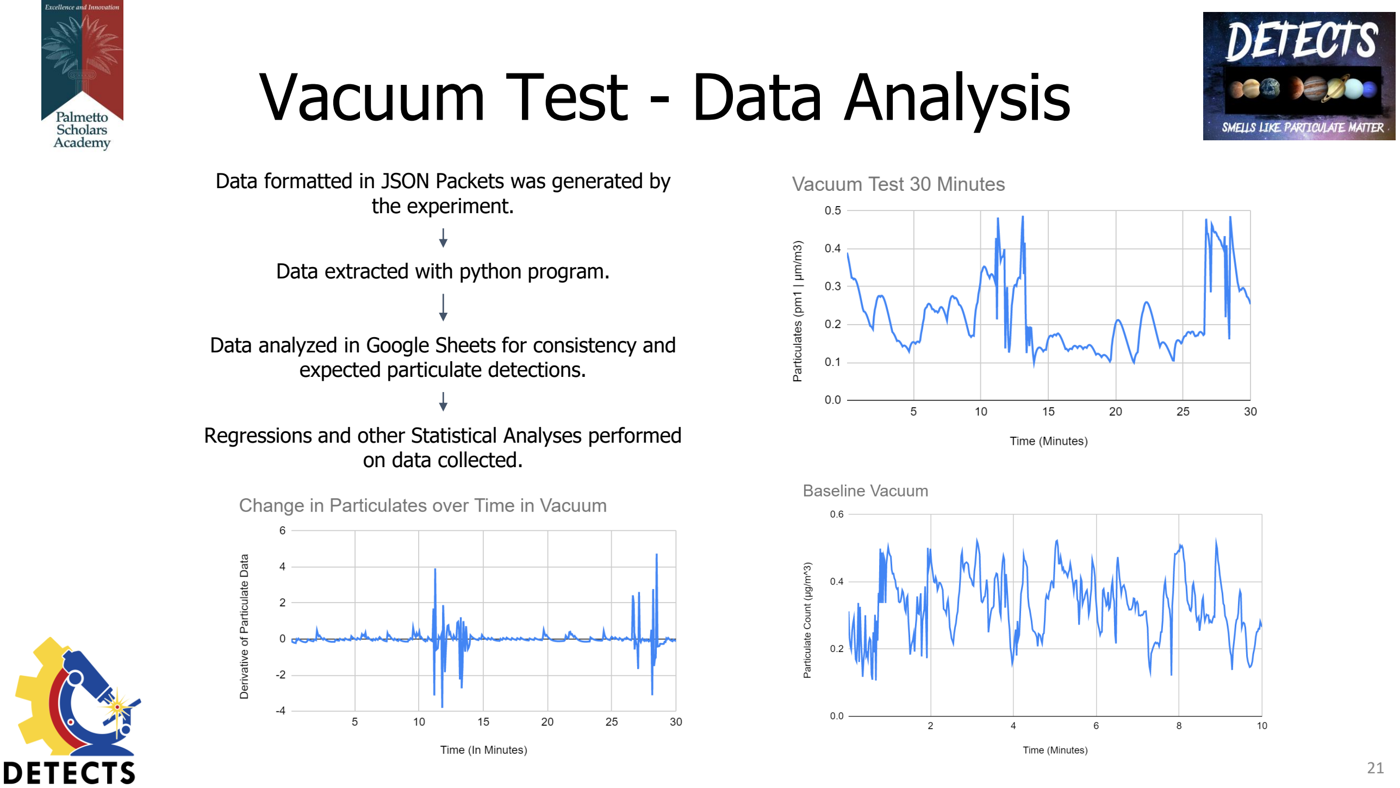
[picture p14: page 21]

Data formatted in JSON Packets was generated by the experiment.

Data extracted with python program.

Data analyzed in Google Sheets for consistency and expected particulate detections.

Regressions and other Statistical Analyses performed on data collected.

Personal Protective Equipment
- Clothing:
- Lab Coat
- Safety Goggles
- Heat Resistant Gloves
- Other Equipment:
- Fire Extinguisher
- Fume Hood
- ESD wristband (while handling pi)

Testing Environment/Plan
- Clean oven before test.
- Test each part of experiment (wires, board, SPS30) individually for 1 hour at 90℃.
- Preheat for 30 minutes for assembled test (90℃).
- Test assembled experiment at 90℃ for 1 hour.
- Power with external power source.
- Verify functionality by introducing particle source.
- Allow to cool to 30℃ before removing.

# Heat Test

Requirements to Meet
- UAH Requirements:
- Survive up to 90℃.
- Take measurements, organize data packets, and send data.
- Team Requirements:
- Survive 90℃ for 1 hour.
- Meet all functional requirements.

Results
- Wires | = | Completed
- Board | = | Completed
- SPS30 | = | Completed
- Full Configuration | = | Completed
- More Details:
- Use a container with particulates to verify functionality in heat.
- Open ssh on pi for alternative to HDMI cable. | 22

# Heat Test - Evidence

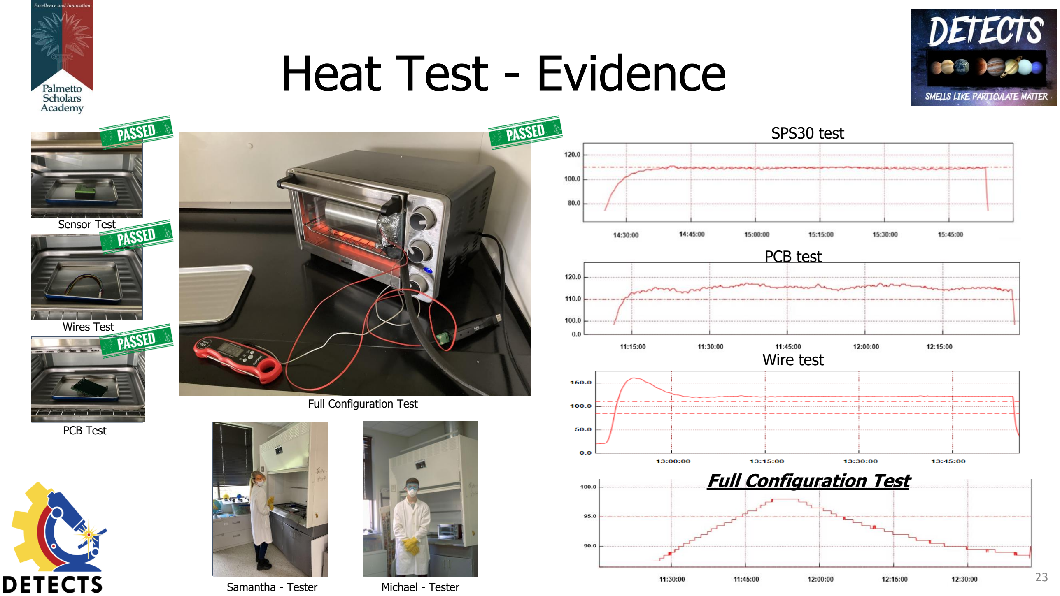
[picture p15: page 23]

Full configuration in oven

sensor in oven

Wires in oven

Board in oven

Tester’s
picture?

Tester’s
picture?

PCB test

SPS30 test

Wire test

Samantha - Tester

PCB Test

Full Configuration Test

Michael - Tester

Wires Test

Sensor Test

Full Configuration Test

# Heat Test - Data Analysis

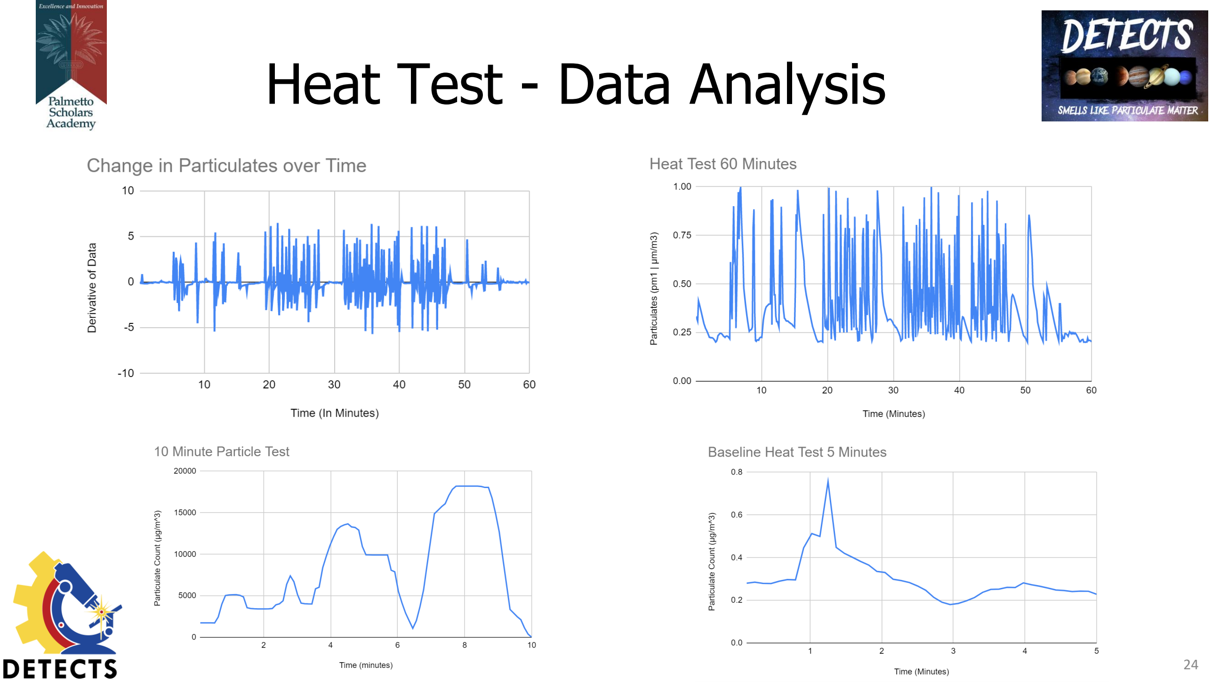
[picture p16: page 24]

Personal Protective Equipment
- Clothing
- Lab Coat
- Safety Goggles
- Gloves
- ESD wristband (while handling pi)

# Cold Test

Requirements to Meet
- UAH Requirements:
- Survive temperatures as low as -20℃.
- Take measurements, organize data packets, and send data.
- Team Requirements:
- Survive -20℃ for 1 hour.

Testing Environment/Plan
- Set freezer to -20℃, allow 30 minutes to cool.
- Test each part of experiment (wires, board, SPS30) individually for 1 hour at -20℃.
- Test assembled operational experiment at -20℃ for 1 hour.
- introduce particulates using a sealable container.
- Remove using protective gloves.

Results
- Wires | = | Completed
- Board | = | Completed
- SPS30 | = | Completed
- Full Configuration | = | Completed
- More Details:
- The team ran a sensor test at -20℃, and the sensor was able to function accurately.

# Cold Test - Evidence/Results

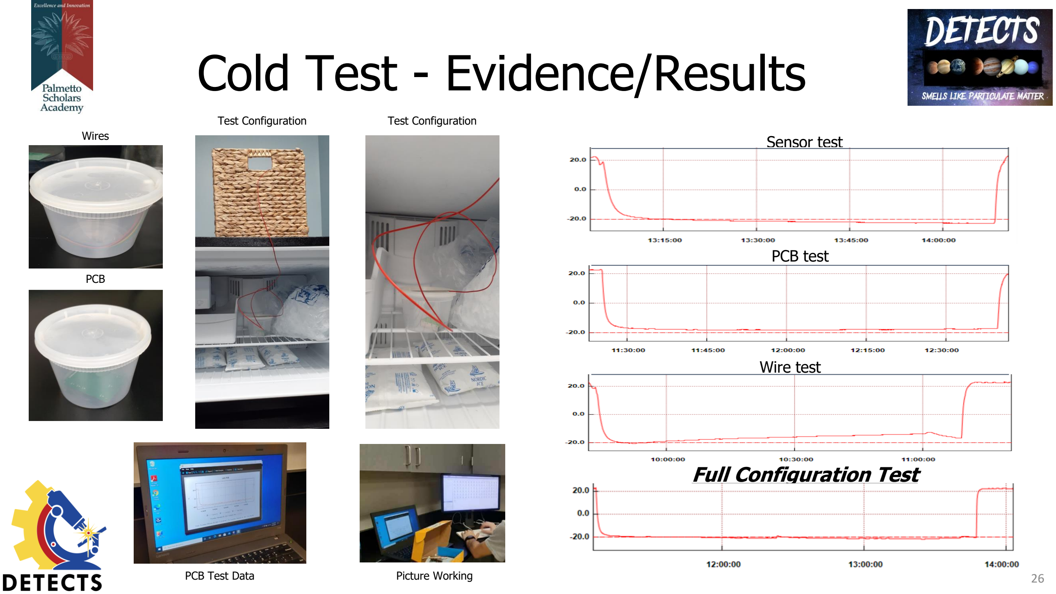
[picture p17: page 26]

PCB test

Sensor test

Wire test

Full Configuration Test

PCB Test Data | Picture Working | 26
Test Configuration | Test Configuration
Wires

PCB

# Cold Test - Data Analysis

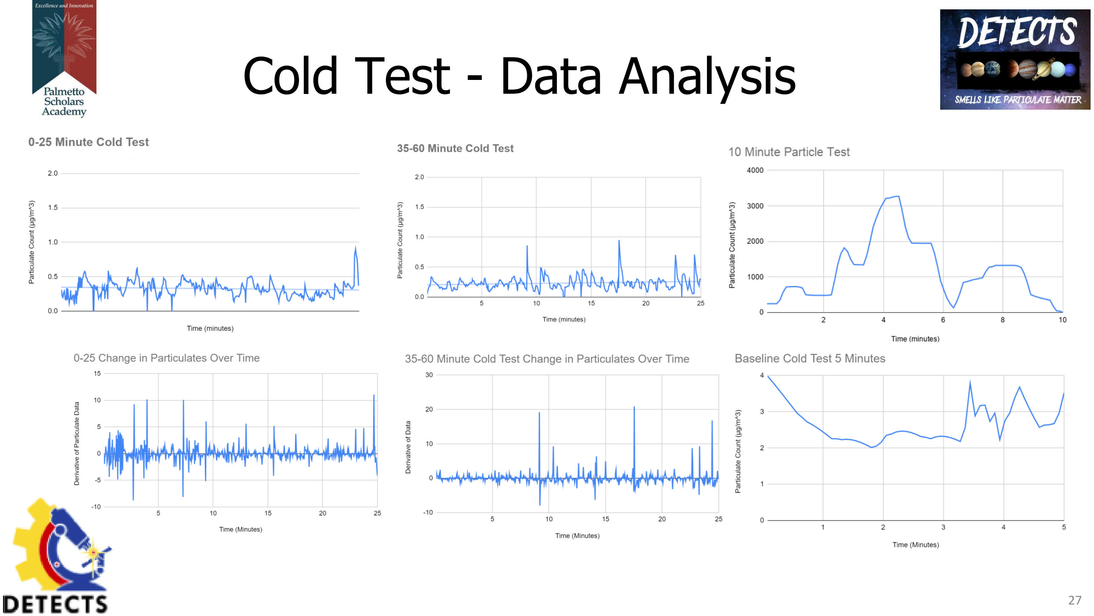
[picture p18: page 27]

Personal Protective Equipment
- Clothing
- Lab Coat (while in lab)
- Gloves (while handling pi)
- ESD wristband (while handling pi)

Testing Environment/Plan
- Check integrity of parts beforehand
- Use dampeners and rubber mallet to create random acceleration.
- Follow Vibration testing handout.
- Mount experiment to wood.
- Connect accelerometer to computer with usb extension cable.
- Inspect for damage after test.

# Random Vibration Testing

Requirements to Meet
- UAH Requirements:
- Survive random vibrations up to 4 gs.
- Take measurements, organize data packets, and send data.
- Team Requirements:
- Survive 4 gs for 15 minutes.

Results
- Full Configuration Test | = | Completed
- More Details:
- Be extra cautious with experiment while not in lab environment.
- Hit wood into foam eggcrate at different angles.
- Be careful not to hit fingers.

# Vibration Test - Evidence/Results

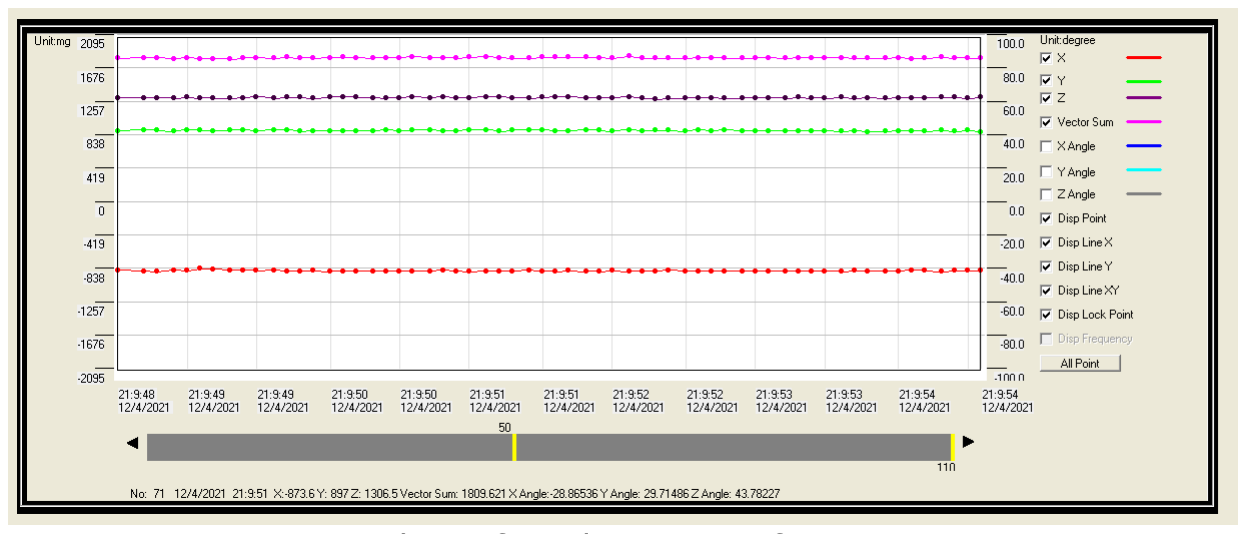
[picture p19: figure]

Photo of Accelerometer Software | Experiment on Wood
| Calibration Value | Math | G
X-Axis | -877 mg | 877 + 6377 6503 - 877 | 7.254 5.626
Y-Axis | 884 mg | -884 + 7965 884 + 7107 | 7.081 7.991
Z-Axis | 1305 mg | -1035 + 8765 1035 + 6440 | 7.730 7.475

Accelerometer Data

# Vibration Test - Data Analysis

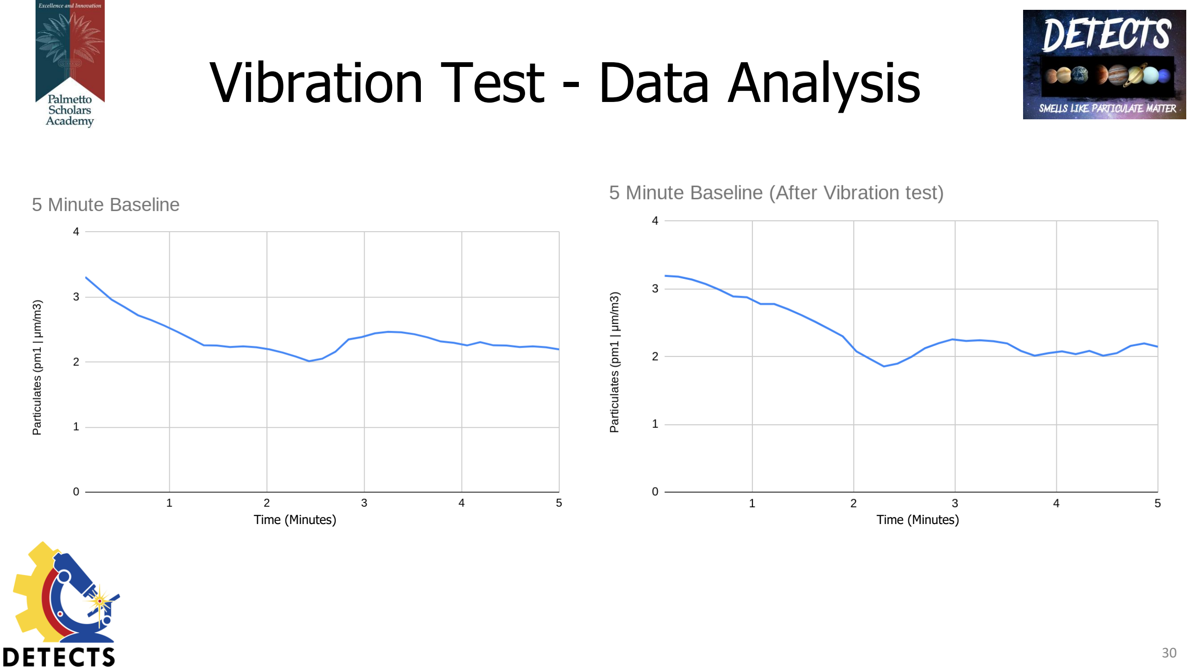
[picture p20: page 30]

Time (Minutes) | Time (Minutes)

# Requirements Compliance

Requirement | Verification | Compliance
Take Measurements | Functionally tested with the sensor test.
| Tested Pi HAT measurement capabilities in different environmental conditions
Organize Data Packets | Functionally tested with transfer test.
Send Packets | Tested the data transfer via the transfer test.
Establish Accurate particulate count | Functionally tested the particulate matter sensor via environmental and sensor tests.
Handle Program Errors | Functionally tested with the recovery test.
Resume operation after reboot | Functionally tested with the recovery test.

# Requirements Compliance (cont.)

Requirement | Verification | Compliance
Survive hot temperatures (Survive 90C for 1 Hour) | Experiment passed Heat Test by operating at 90C for 1 hour.
Survive cold temperatures (Survive -20C for 1 Hour) | Experiment passed Cold Test by operating at -20C for 1 hour.
Survive extreme pressure (Survived vacuum for 30 minutes) | Experiment passed Vacuum Test by operating in a vacuum for 30 minutes.
Survive Random Vibrations (Survived 4g of Vibration for 15 minutes) | Experiment passed Vibration test by surviving 4 g of random vibration for 15 minutes.

# ICD Compliance

Requirement | Verification | Compliance
No larger than 65 x 56.5 x 19 mm | Experiment dimensions of 65 x 56.5 x 18.8 mm
Securely mounted to the Pi | Survived 4g of random vibrations (verified by Vacuum test)
Interfaces with the 40-pin GPIO header on a Raspberry Pi 3B+ | Uses Pi HAT to interface with the 40-pin GPIO
5 kilobytes per second or smaller data rate | 0.5kBps data rate verified with the Transfer Test
JSON formatted data packets delivered to the /tmp/experiment/ folder | Successful packet transfer verified with Transfer Test
No potential harm to AR2B mission | Meets All Requirements set forth by AR2B

# Online Outreach

# Outreach Plan

Our goal, as a team, is to create an online presence to engage and inform viewers about DETECTS and our team. This will be done by sharing both informative and fun videos on our main platform Youtube.

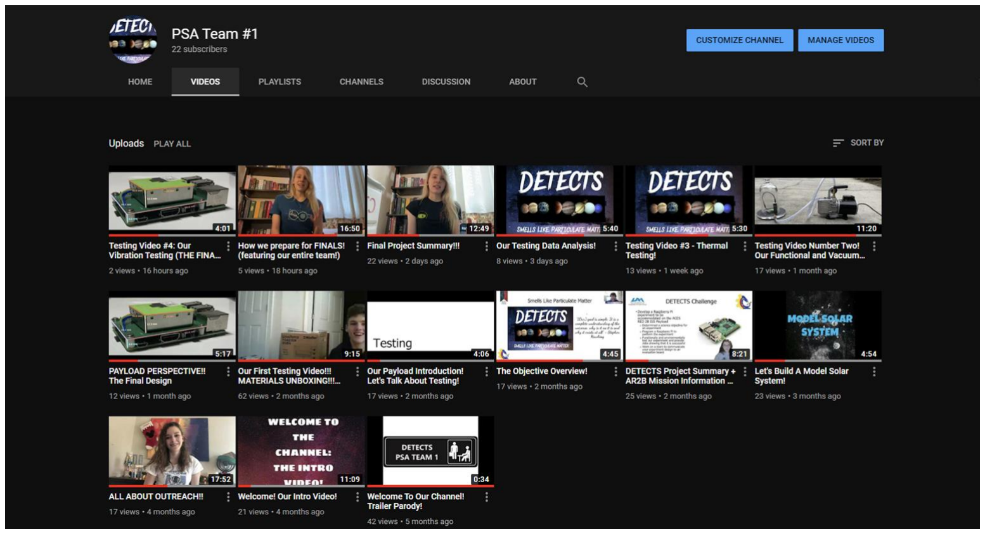
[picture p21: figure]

Our platform choice was based on our contents topic, targeted demographic, team dynamic, ability to have creative freedom, and the popularity of the platform.

# Outreach Videos

- “Welcome To Our Channel” Trailer
- “Our Introduction Video”
- “All About Outreach!”
- “Let’s Build A Model Solar System!”
- “DETECTS Project Summary + AR2B Mission

Information”

- “The Objective Overview”
- “Our Payload Introduction! Let’s Talk About

Testing”

- “Our First Unboxing Video! MATERIALS

UNBOXING!”

- “Payload Perspective! The Final Design”
- “Testing Video #2: Our Functional and Vacuum

Testing”

- “Testing Video #3: Thermal Testing!”
- “Our Testing Data Analysis!”
- “Final Project Summary!”
- “How We Prepare For Finals!”
- “Testing Video #4: Vibration Testing”
- “Pros & Cons + The Lessons We Learned Along

The Way”

- “Thank You”

# Team Outreach Videos

School
Logo Here

Logo Here

# Outreach Platform Analysis

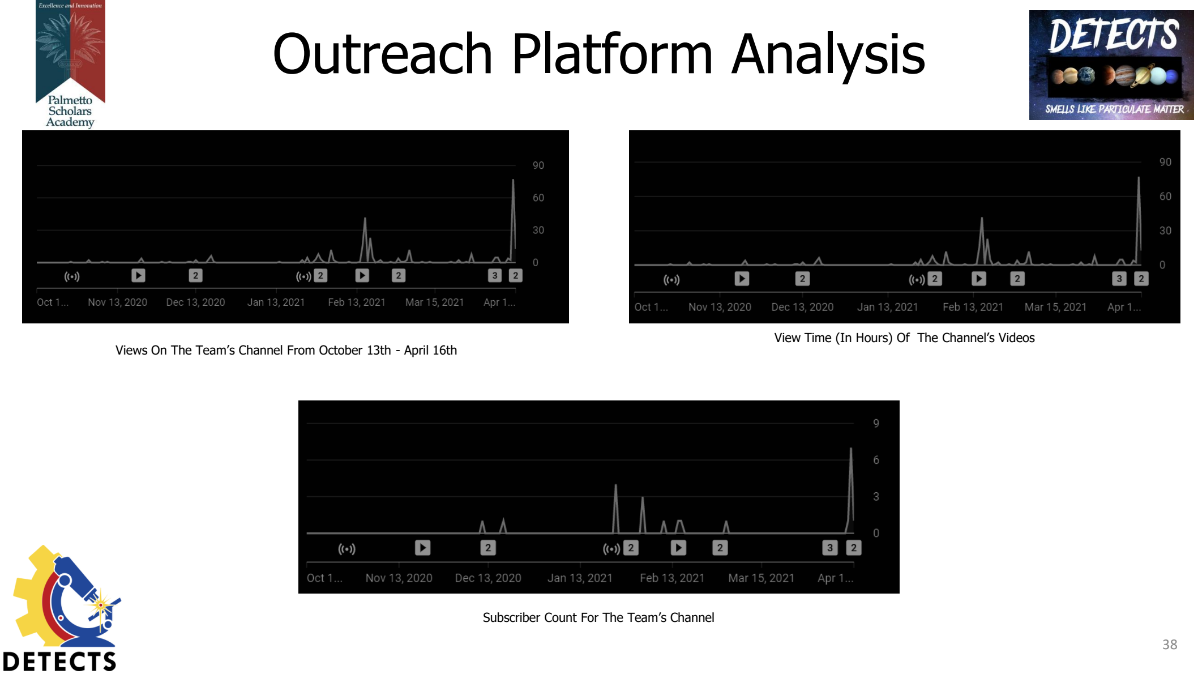
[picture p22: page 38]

Views On The Team’s Channel From October 13th - April 16th

View Time (In Hours) Of The Channel’s Videos

Subscriber Count For The Team’s Channel

School
Logo Here
Team Survey Analysis | Logo Here

Science Importance

| pre-K | 1st | 2nd | 3rd | 4th | 5th | 6th | 7th | 8th | 9th | 10th | 11th | 12th | Adult
Male | 5.333 | 7 | 0 | 6.75 | 7.5 | 6.555 | 7.393 | 7.31 | 6.777 | 6.597 | 7.88 | 8.361 | 7.58 | 9.38
Female | 8.333 | 5.5 | 7.5 | 9 | 8.5 | 7 | 7.454 | 7.742 | 7.648 | 5.96 | 8.192 | 8.186 | 8.062 | 9.461
Other | 0 | 0 | 0 | 0 | 0 | 0 | 3 | 9.666 | 4 | 6.2 | 8.3 | 9.083 | 6.6 | 7

School
Logo Here
Team Survey Analysis | Logo Here

Science Liking

| pre-K | 1st | 2nd | 3rd | 4th | 5th | 6th | 7th | 8th | 9th | 10th | 11th | 12th | Adult
Male | 7.333 | 7 | 0 | 7 | 6.5 | 8 | 6.09 | 5.793 | 6.444 | 6.489 | 6.693 | 7.191 | 7.1 | 7.129
Female | 7.666 | 6 | 9.5 | 9 | 7 | 7.25 | 6.424 | 6.142 | 5.729 | 5.637 | 5.923 | 7.093 | 6.125 | 8.265
Other | 0 | 0 | 0 | 0 | 0 | 0 | 4.333 | 9 | 1 | 5.8 | 7 | 8.5 | 6.2 | 5.666

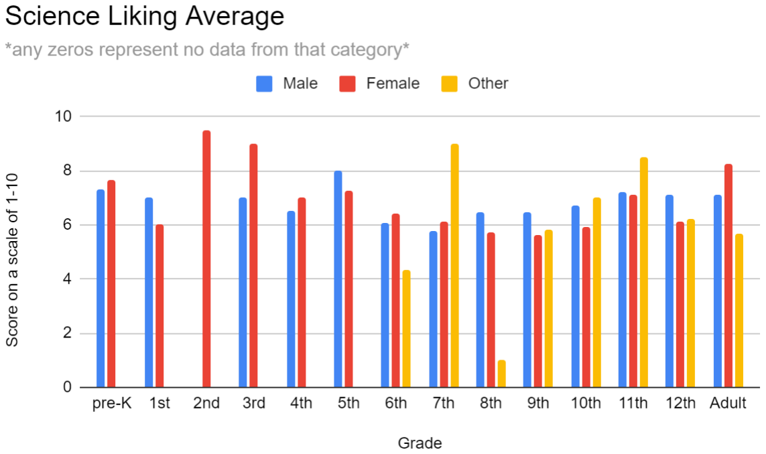
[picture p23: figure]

School
Logo Here
Team Survey Analysis | Logo Here

Math Importance

| Pre-K | 1st | 2nd | 3rd | 4th | 5th | 6th | 7th | 8th | 9th | 10th | 11th | 12th | Adult
Male | 5.666 | 5 | 0 | 7.75 | 8 | 5.222 | 8.459 | 7.793 | 6.576 | 7.382 | 7.88 | 8.625 | 7.322 | 9.283
Female | 5.25 | 4 | 6.5 | 8 | 7 | 6.25 | 7.62 | 8.428 | 8.289 | 7.904 | 7.935 | 7.391 | 7.625 | 9.422
Other | 0 | 0 | 0 | 0 | 0 | 0 | 3.666 | 9 | 3 | 5.4 | 7.777 | 8.833 | 6.6 | 10

School
Logo Here
Team Survey Analysis | Logo Here

Math Liking

| Pre-K | 1st | 2nd | 3rd | 4th | 5th | 6th | 7th | 8th | 9th | 10th | 11th | 12th | Adult
Male | 7.333 | 6 | 0 | 8 | 10 | 5 | 6.636 | 4.758 | 6.629 | 6.5 | 6.746 | 7.391 | 6.483 | 7.788
Female | 6.666 | 4.5 | 9.5 | 4 | 6.5 | 8.75 | 6.281 | 6.352 | 7.054 | 6.32 | 5.564 | 5.956 | 6.2 | 6.93

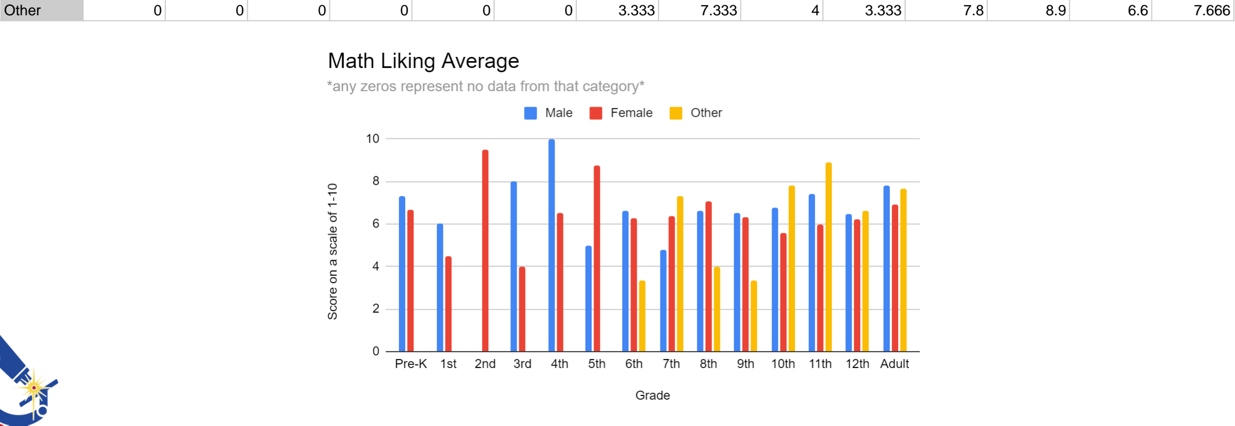
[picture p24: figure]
Other

# Summary

# Lessons Learned

Leadership | Experiment Group | Testing Group | Outreach Group
Learned: Organizational Skills Time Management | Learned: Collaborate Online Enhance Productivity | Learned: Better Communication Importance of Scheduling | Learned: Operate Online Platforms Online Outreach
Problems: Miscommunications early in the semester | Problems: Remote Programming PCB Design | Problems: Remote Testing | Problems: Managing multiple platforms
Future: Work Independently Use Class Time to Collaborate | Future: Programming in Person New program proficiency | Future: Planned testing dates and scheduled Zoom calls | Future: Collaborate with established platforms. Reach out to students at PSA through teachers

# Summary

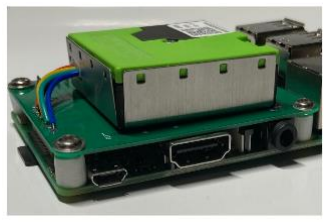
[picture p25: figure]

Design
Summary
- Science Objectives: - | Assess particulate density, prevalence, size, and levels over time - | Compare to currently used particulate sensing equipment • Configuration - | Instruments: SPS30 Particulate Matter Sensor - | PCB is 65 x 56.5 x 0.6mm - | 65 x 56.5 x 18.8mm - | Outputs ~0.3 kBps normally, max 0.5 kBps • 6 Major Program Parts - | Startup, Control, Transfer, Monitor, UAH’s Data Send, and Restart
Outreach | • 1,032 Survey Collected • Youtube - Major Platform -17 videos

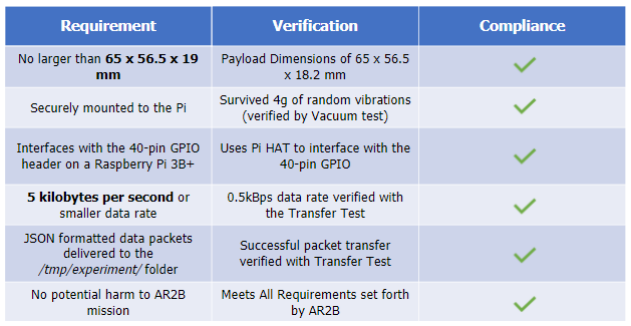
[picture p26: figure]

Testing

- Functional Testing and Requirements – | Sensor - Can detect particulate matter accurately – | Transfer - Max data rate of 0.5kBps – | Recovery - Experiment recovered from all conceived scenarios • Environmental Testing and Requirements – | Vacuum - Operated in vacuum-like conditions for 30 minutes. – | Heat - Operated in temperatures up to 90℃ for 1 hour. – | Cold - Operated in temperatures down to-20℃ for 1 hour. – | Vibrational - Survived random vibrations up to 4gs for 15 minutes.

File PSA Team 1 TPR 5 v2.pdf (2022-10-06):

# Team Progress Report 5

## Smells Like Particulate Matter Palmetto Scholars Academy Team 1


School
Logo Here

Team
Logo Here


Test Lead
Emann
Rivero
12th Grade

Chief Engineer
Samantha
Quartuccio
12th Grade

Experiment Lead
Max
Freedman
11th Grade

Experiment Group
Benjamin
Deaton
11th Grade

Team Lead
Michael
Blunt
11th Grade

Test Group/Outreach
Morgan
Peterson
11th Grade

# Team Smells Like Particulate Matter Logo Here


School
Logo Here

# “[Our] goal is simple. It is a complete understanding of the universe, why is it as it is and why it exists at all” - Stephen Hawking

School
Logo Here
Team ACES RED 2B | Logo Here


## - Studying quantum entanglement for space satellite

communications.

## oSponsored by U.S. Space and Missile Defense Command (SMDC)

## - Secondarily investigating the use of low-cost

## commercial-off-the-shelf (COTS) hardware

## oTo replace currently used expensive equipment oPrimary objective of DETECTS

School
Logo Here
Team Design Requirements | Logo Here
Mechanical/Spatial Requirements | Electrical Requirements
- Must be no larger than 65x56.5mm ● Must be less than 19mm above the surface of the Pi when plugged in | ● NO High-voltage-inducing instruments (over 28 V) ● Pinout used must be the one found on the Pi ● Pins 30 and 31 cannot be used
Material Requirements | Software Requirements
- NO Mechanisms or moving parts
- NO Liquids, gases, or fluids of any kind
- NO Organic material or any other exotic material
- NO Vibrating/oscillating components
- NO Loose/powdered material
- NO Batteries or electrolytic capacitors
- Must be developed on a Raspberry Pi 3B+
- Must operate the Pi HAT and gather data from it
- Data rate must NOT exceed 5 kilobytes per second
- Must communicate with the AR2B flight computer via JSON formatted packets
- Transfer JSON packets into a folder called /tmp/experiment/ in the Raspberry Pi’s file system
- Must include an identifier within the JSON packet

# Experiment

School
Logo Here
Team Chosen Science Objective | Logo Here

## - Commercial-Grade Contaminants Comparison

- Establish an experiment that can compare the quality and quantity of data accumulated from commercial-grade and professional-grade particulate matter sensors.
- Assess particulate density, prevalence, size, and levels over time in ACES RED 2B using consumer-grade sensors

# Team Experiment Configuration Logo Here

School Logo Here

School
Logo Here
Team Concept of Operations | Logo Here

Phase 1; • Powers on (crontab).; • Turn on SPS30; ensure data flow.; Phase 2; Phase 3; • Analyze results. • Write a report outlining findings.

- Launches all other programs in a structured order.
- Continuous operation with a 12 hour (on) 2 minute (off) cycle.
- Verifies continuous program functionality with a monitor program.
- Sends data until 14 days before AR2B end-of-life cycle.
- Before AR2B end date, send last packet and poweroff.

# Testing

School
Logo Here
Team Testable Requirements | Logo Here

Functional
Requirements

Take Measurements

Organize Data Packets

Send Data

Establish Accurate
Particulate Count

Handle Program Errors

Resume Operation After
Reboot

Environmental
Requirements

Survive Hot Environment

Survive Cold Environment

Survive Extreme Pressures

Survive Random Vibrations

Maintain Structural Integrity

School
Logo Here

Team
Logo Here

## General Safety Practices

- Use proper Personal Protective Equipment (PPE).
- Have proper emergency equipment available.
- Ensure proper electrostatic discharge (ESD) protection.
- Use ground-fault circuit interrupter equipped (GFCI) outlets.
- Maintain clear and safe lab environment.
- Clean all equipment before and after use.

## Hazard Avoidance

- Use N95-mask and fume hood to avoid possible inhalation of fumes.
- Verify equipment works before testing. (fume hood)
- Verify integrity and oil level of vacuum pump before and after use.
- Additional examples of hazard avoidance will be listed under the respective tests.

# Safety Plan

School
Logo Here

# Team Functional Test - Transfer Test Logo Here

Test Overview
- Demonstrates that program can organize and send data packets.
- Used UAH’s and team transfer program.
- Verify data collected is organized and transferred to UAH’s data handling program.
- Test completed 25 times, 0 failures.
- Pi was rebooted via various stimuli (see Recovery test).

Results
- Pass
- The programs all worked as expected, data was transferred in time stamped files to /tmp/experiment/
■ Max of 0.5 kBps, average of ~0.3 kBps ■ Example from UAH transfer program:


- A picture of the
populated
/tmp/experiment/
folder after a run
with the UAH
program disabled.

Evidence

Requirements to Meet
- UAH Requirements:
- Take measurements, organize data packets, and send data.
- Data rate of less than 5.0 kBps.
- Communicate with AR2B flight computer via /tmp/experiment/.

School
Logo Here

# Team Functional Test - Recovery Test Logo Here

Test Overview
- Demonstrate that program can handle errors and resume operation at reboot.
- Errors tested: Unplugging SPS30 GPIO data wires, cycling power, killing programs, restarts, shutdowns
- Test completed 25 times, 0 failures.
- All program-triggered restarts are called by a monitor program

Results
- Pass
- All programs worked as expected, always started back up after reboot.
■ The monitor program was able to detect and recover from all conceived errors. ■ Note: UAH transfer program disabled after successful relaunch to get evidence.


Evidence
- A picture of the
populated
/tmp/experiment
folder after a run
with the UAH
program
disabled.

Requirements to Meet
- UAH Requirements:
- Take measurements, organize data packets, and send data.
- Team Requirements:
- Handle program errors
- Resume operation after reboot

School Logo Here; Team Logo Here; Test Overview; ○ Connected directly to GPIO header; count; measure particulate matter; matched expected results.; Results; ● Pass; collected with no errors ■ No errors with I²C connection ■ Data was accurate ■ Everything functioned as expected; Evidence; Functional Test - Sensor Test; Requirements to Meet • UAH Requirements:; send data. • Team Requirements:

- Verify the sensor is accurate and functional.
- Verify the sensor can establish an accurate particle
- Sensor placed 6 inches above a lighter to
- Particulate count was steady, and output
- The programs all worked as expected, data was
- Take measurements, organize data packets, and
- Establish an accurate particulate count

School
Logo Here

Team
Logo Here

Test Reasoning
- Demonstrates that the payload can survive in extreme temperatures.
- Show that the payload can operate and produce accurate data in a heated environment.

Personal Protective Equipment
- Clothing
- Lab Coat
- Safety Goggles
- Heat Resistant Gloves
- Ground Cable
- Other Equipment
- Fire Extinguisher
- Fume Hood

Testing Environment/Plan
- Clean oven before test.
- Test each part of payload (wires, board, SPS30) individually for 1 hour at 90℃.
- Preheat for 30 minutes for assembled test (90℃)
- Test assembled operational payload at 90℃ for 1 hour
- Power with external power source
- Allow to cool to 30℃ before handling

# Extreme Heat Testing

Requirements to Meet
- UAH Requirements:
- Survive up to 90℃.
- Take measurements, organize data packets, and send data.
- Team Requirements:
- Survive 90℃ for 1 hour.
- Meet all functional requirements.

School
Logo Here

# Team Heat Test - Results/Evidence Logo Here

Full configuration in oven

sensor in
freezer

Wires in
freezer

Board in
freezer

Placeholder Graph

Tester’s
picture?

Tester’s
picture?

PCB test

SPS30 (green plastic) test

Wire test

Placeholder Graph

Full Configuration Test

School
Logo Here

Team
Logo Here

Test Reasoning
- Demonstrate the payload’s ability to survive in drastically lower temperatures
- Demonstrates that the sensor will work properly in temperatures as low as -20℃

Personal Protective Equipment
- Clothing
- Lab Coat
- Safety Goggles
- Gloves
- Ground Cable

# Extreme Cold Testing

Requirements to Meet
- UAH Requirements:
- Survive temperatures as low as -20℃.
- Take measurements, organize data packets, and send data.
- Team Requirements:
- Survive -20℃ for 1 hour.
- Meet all functional requirements.

Testing Environment/Plan
- Set freezer to -20℃, allow 30 minutes to cool.
- Test each part of payload (wires, board, SPS30) individually for 1 hour at -20℃.
- Test assembled operational payload at -20℃ for 1 hour.
- Power with external power source.
- Remove using protective gloves.

School
Logo Here

Team
Logo Here

Full configuration in freezer

sensor in
freezer

# Cold Test - Evidence/Results

Placeholder Graph

PCB test

Sensor test

Placeholder Graph

Wire test

Wires in
freezer

Board in
freezer

Tester’s
picture?

Tester’s
picture?

Full Configuration Test

School
Logo Here

Team
Logo Here

Test Reasoning

- Demonstrate that the payload can survive and operable while experiencing random vibrations

Personal Protective Equipment
- Clothing
- Lab Coat (for in lab)
- Insulated Gloves
- Ground Cable

Testing Environment/Plan
- Check integrity of parts beforehand
- Place in centrifuge to place experiment under high G forces
- 1 hour of continuous unidirectional acceleration.
- Bumpy South Carolina back roads
- 30 minutes of random but gentler acceleration.
- Vigorously shake pi by base
- 15 minutes of extreme random acceleration.

# Random Vibration Testing

Requirements to Meet
- UAH Requirements:
- Survive random vibrations up to 4 gs.
- Take measurements, organize data packets, and send data.
- Team Requirements:
- Survive 4 gs for 1 hour.
- Survive random vibrations.
- Meet all functional requirements.

School
Logo Here

Team
Logo Here

Config in centrifuge

Misc Picture

# Vibration Test - Evidence/Results

Misc picture

Gravel Lot by CSC | Mounte d payload

Testers
Shaking
payload

Car Data

Shaking Data (might be weird looking)

Centrifuge Data

School
Logo Here

Team
Logo Here

Test Reasoning

- Demonstrate that the payload can maintain structural integrity and remain operable in vacuum-like conditions

Personal Protective Equipment
- Clothing
- Lab Coat (for in lab)
- Insulated Gloves
- Ground Cable
- Safety Goggles
- Equipment
- Fire Extinguisher
- GCFI protected outlet
- Other UAH guidelines?

Testing Environment/Plan
- Change oil and inspect vacuum chamber for defects
- Test each part of payload (wires, board, SPS30) individually for 1 hour.
- Follow steps in vacuum testing handout.
- Test assembled payload with battery for 30 minutes.
- Allow repressurization of chamber, and repeat test.

# Vacuum Testing

Requirements to Meet
- UAH Requirements:
- Survive vacuum.
- Take measurements, organize data packets, and send data.
- Team Requirements:
- Survive 4 gs for 1 hour.
- Survive random vibrations.
- Meet all functional requirements.

School
Logo Here

Team
Logo Here

Config in Vacuum Chamber

# Vacuum Test - Evidence/Results

Full setup with
pump in frame

Testers

Particulate Data - Test 1

Particulate Data - Test 2

Particulate Data - Test 3

sensor in vac
chamber

Wires in vac
chamber

Board in vac
chamber

# Online Outreach

School
Logo Here

# Team Outreach Plan

Logo Here

Our goal, as a team, is to create an online presence to engage and inform viewers

about DETECTS and our team. This will be done by sharing both informative and fun

videos on our main platform Youtube.


Our platform choice was based on our contents topic, targeted demographic, team dynamic, ability to have creative freedom, and the popularity of the platform.

School
Logo Here

Team
Logo Here

# Outreach Content So Far

Color Key

Activity Or Demonstration Video

Discussion Or Presentation Style Video

Video Topic Created By Our Team

Date | Title | Content Requirement
October 26th, 2020 | Channel Trailer | None ~Added By Our Team~
November 21st, 2020 | General Introduction Video | DETECTS Project Summary
December 13th, 2020 | All About Outreach | None ~Added By Our Team~
December 19th, 2020 | Let’s Build A Model Solar System | Activity/Demonstration related to our Objective
January 23rd, 2021 | DETECTS Project Summary + AR2B Information | DETECTS Project Summary AR2B Mission Overview
January 30th, 2021 | The Objective Overview! | Potential Science Objectives Selection Process Visual Demonstration/Explanation for Experiment Design
February 3rd, 2021 | Payload & Testing Introduction | Summary of Design Process Explanation of the Testing Process
February 15th, 2021 | Testing Video #1: Materials Unboxing! | None ~ Added By Our Team~

School
Logo Here

Team
Logo Here

# Planned Outreach Content

Upcoming Videos

Date | Title | Content Requirement
February 27th | Payload Breakdown | Summary of Design Process - Image + Description content Demonstration For Pi
February 27th | Testing Video #2 - Sautering - Thermal Testing - Heat Test - Chill Test - Functional Testing | Explanation of - Functional Testing - Thermal Testing Functional & Thermal Testing Content Demonstration For Testing + Pi


March 6th, 2021 | Testing Video #3 - Vacuum Test - Rumble Test | Explanation of - Vacuum Testing - Vibration Testing Vacuum Testing Content Vibration Testing Content Demonstration For Testing


March 13th, 2021 | Testing Result Analysis + Data! | Data Analysis
March 20th, 2021 | Project Summary | Project Summary
March 27th, 2021 | Project Pros & Cons + Lessons Learned | Pros & Cons Lessons Learned
April 3rd, 2021 | Q + A Video | None ~Added By Our Team~
April 10th, 2021 | How We Prep For Final Review | None ~Added By Our Team~
April 17th, 2021 | Thank You Video - A Message To Our Viewers | None ~Added By Our Team~

# Sensor Problems

School
Logo Here

Team
Logo Here

# Sensor Problems

The Solution
Identify limiting component(s), remedy problem.
#1 - Internal Fan

#2 - Plastic Components

These are not the only ideas I have considered, just the ones worth mentioning. I would really appreciate any thoughts or other ideas you may have on the subject!

The Problem
SPS30 datasheet says temperature limits of SPS30 are -10℃ to 60℃

School
Logo Here

Team
Logo Here

# Problem - Internal Fan


After hours of searching and thinking, I think I finally figured out the problem.

The SPS30 has a thermal limitation of -10℃ to 60℃. I was not able to find the datasheet for the exact model fan used in the SPS30 (MF20060V2-1C010-G99) The SPS30’s internal fan has a thermal limitation of -10℃ to 70℃.


During thermal testing (by the fan manufacturer) of similar internal fans, they only tested their fans at 70℃ for 2 hours, and they reported decreased efficiency near temperature extremes (~5 to -10, and ~55 to 70).

School
Logo Here

Team
Logo Here

# Solution - Internal Fan

In a vacuum, a fan has no purpose.

I already created a call to disable the fan when I created the sensor interface program last semester.

The fan itself is still inside of the SPS30, but its can be disabled both physically and digitally.

The SPS30 does not need a fan to function, rather, it facilitates the transport of particles into the sensor. In addition, the payload will be in an enclosed environment, in microgravity, in vacuum conditions, where there will be no need for an additional catalyst of particle movement.

School
Logo Here

Team
Logo Here

# Plastic Components

The SPS30 is almost entirely plastic components, and I was initially worried that they might deform under heat.

When I took the top green piece of plastic off the SPS30, it looked very solid and I decided to test it.

It survived the oven at 110℃ for ~1:15, leading me to believe that the plastic is not the problem.

The plastic fit normally back into place on the sensor,


no problems were noted. | SPS30 (green plastic) test

School
Logo Here

Team
Logo Here

# Solution - Plastic Components


If the plastic components prove to still be a problem, we can still work around this.

The SPS30 comes apart completely into PCB, laser, and plastic pieces, respectively.

We can complete a 3D scan of all of the plastic pieces and convert that scan into a CAD model. There are services that will do this professionally and there are also applications that turn photo/video into a CAD model.

We can then reprint the pieces with a more heat resistant material like nylon, aluminum, etc.

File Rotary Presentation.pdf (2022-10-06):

# Space Station Experiment


## Michael Blunt and Morgan Peterson Palmetto Scholars Academy

# Introductions


7 years at PSA

3 years in MD

### Project Manager of AR2B Secondary Objective Intended Major: Computer Science

### Outreach Lead of AR2B Secondary Objective Intended Major: Astronautical Engineering

3 years at PSA

3 years in MD

What is D.E.T.E.C.T.S.


# Highschool teams from across the country compete for a research slot on a payload traveling to the International Space Station

(ISS).

# Teams design, engineer, model, build, test, and present project proposals to boards of

engineers, project managers, and scientists.

# The DETECTS competition is hosted by the University of Alabama in Huntsville (UAH). The competition is funded by the Space and Missile

Defense Command (SMDC) and NASA.

# The AR2B Mission

# The DETECTS mission is a secondary objective, and

# will be launched alongside a quantum entanglement

experiment studying space satellite communications.
- The entire mission is called AR2B.

# Objective of DETECTS: - Find viable low cost equipment to replace current


expensive equipment.


https://space.skyrocket.de/doc_lau/falcon-9.htm

# Deliverables

# As part of the evaluation process, teams were required to complete the following over 12 months:

# - Progress Report Presentations (6x) - 10 page formal reports (2x) - Board Reviewed Presentations (2x) - Create Outreach Platform & Content (12 Required Topics) - Collect Online Outreach Data (500+ Surveys)

# The Mission Design Process

# Requirements and Limitations

## Requirements:


## - Understand different engineering and design

requirements.

## Solutions:

- Identifying needed equipment.

## - Applying understanding of requirements during

design process.

## Ramifications:

- Technical documentation.
- Real world engineering ramifications.
- Technical communication to large audiences.
- Verification of requirements to boards.

# Selecting Objectives


## Requirements: - Select a science objective for your

payload.

## Solutions:

- Create Potential Science Objectives.
- Create weighted figures of merit.
- Research proposed objectives.
- Use trade studies to evaluate.

## Ramifications:

- Research skills.
- Team-based communication skills.
- Standardized evaluations.

## Requirements:


- Prototype a payload that fulfills all requirements.

## Solutions:

- Iterative design process.
- Modeling and Simulation.


- Physical assembly and advanced construction.

## Ramifications:

- Application of our requirements understanding.
- Industry software proficiency.
- Knowledge of hardware.

# Building Experiments

# Revisit Design Process

## Requirements:


## - Refine design based on physics and engineering

analysis.

## Solutions:

- Utilization of high-level mathematical formulae.

## - Understanding relationship between assumptions

and outcomes.
- Organized and repeatable mathematical proofs.

## Ramifications:

- Applied mathematics proficiency.
- Creativity in overcoming challenges.
- Describing findings coherently to all audiences.

# Activities for Community Engagement (A.C.E.)

# A.C.E. Outline

A.C.E:


A.C.E. is embodied by four elements:


- Identity
- Outreach
- Create and run an online platform over the course of the competition
- Complete Content Checklist
- Events + Surveys
- Plan, host, and run at least 3 Outreach Events
- Collect and analyze data on:
■ Science Liking
■ Science Importance
■ Math Liking
■ Math Importance
- Effort
- Your ACE must be “successful”
- Exceed minimum requirements


“For here am I sitting in
my tin can, far above the
world”
David Bowie

# Identity

Requirements:

- Design and create a team identity consisting of of a name, slogan, and logo

Solutions:

- Create an identity that connects to the mission in some way
- Use inspired ideas from pop culture or scientific fun facts about the mission

Ramifications:

- Logo marketing to audiences
- Communication of an identity and idea

# Oh, such a timeless flight

# Elton John

## “[Our] goal is simple. It is a complete understanding of the universe, why is it as it is and why it exists at all”

## Stephen Hawking


# Outreach


14

Our goal was to create an online presence to engage and inform viewers about DETECTS and our team. This will be done by sharing both informative and fun videos on our main platform Youtube.

Our platform choice was based on our contents topic, targeted demographic, team dynamic, ability to have creative freedom, and the popularity of the platform.

At the end of the competition we had created 18 videos specifically for DETECTS.

# Outreach

Requirements:

- Through the use of social media platforms, introduce facts about our mission, our team, and about STEM

Solutions:

- Create social media accounts using our team identity
- Come up with and create interesting posts and videos
- Collect surveys from followers and viewers


Ramifications:

- Use of social media analytics through business accounts
- Introduction to online media marketing and coordination

# Events


Requirements:

- Host in-person events in which we introduce our audiences to Mission Design, STEM, and Aerospace Engineering

Solutions:

- Use fun experiments to introduce audiences to the topics of STEM
- Create a poster board which we can use to explain various aspects of our mission

Ramifications:

- Communication to in-person audiences
- Interactive presentation skills

### School Logo Here


### Team Logo Here

# Effort: End of Competition Platform Analysis

End of Competition Statistics:

481 Views

- Most view traffic came from Channel Pages and Browser Recommendations
- All our viewers were from the United States of America
- Our viewers all fell into the 18-24 age category
- It was 50-50 between our viewers being subscribed and unsubscribed

12.7 Watchtime (Hours)

24 Subscribers

2,599 Impressions

Highest Performing Videos of the Competition:

- Our First Testing Video (Materials Unboxing)
- Thank You & Goodbye for Now
- We Won!

# My Channel Now

Current Channel Statistics:

1,580 Views

- Most view traffic came from Channel Pages, Browser Recommendations, and Youtube Search
- The channel has viewers in the United States, Austria, and the United Kingdom
- Viewers still fall into the 18-34 age category
- Audience is primarily Female

62.7 Watchtime (Hours)

49 Subscribers

14,062 Impressions

My highest performing videos to date:

- My Jaw Surgery Story
- Nutcracker Vlog
- Our First Testing Video (Materials Unboxing)
- How I Improved My SAT Score

# Our Project

# Research/Problem

## - Research Question oWhat is the difference in both quality and quantity of measurement between consumer and professional-grade sensing technology?

## - Hypothesis

## oLaser based consumer-grade particulate matter sensors are more accurate

than existing professional-grade infrared particulate matter sensors.


## - Research

## oANITA, developed in the early 2000s for ISS

## - > 0.7 μm (high parts per billion) - Infrared

## - > 0.3 μm (low parts per billion) - Laser

# Process Summary


40.6mm

USB Ports for
reference

USB Ports for
reference

Ethernet Port
for reference

# We spent the first six months of our project designing and building our experiment. This included: - Researching - Programming - Modeling - Integrating - Assembling The remaining six months were spent

testing and perfecting our experiment.

# End Result


40.6mm

USB Ports for
reference

USB Ports for
reference

Ethernet Port
for reference

# We were given a final review score of 99.7%, and were selected as the only

experiment travelling with AR2B.

# - We were published in the Post and

Courier, and made the front cover.

# - Many members of the local community saw this article, and it has helped create awareness of the opportunities STEM competitions in

high school have to offer.

# Tools for the Future

40.6mm

USB Ports for
reference

USB Ports for
reference

Ethernet Port
for reference

### Michael: - Early leadership experience will allow me to perform as a more experienced leader in future

situations.

### - CAD and programming knowledge will be

incredibly useful as a CS major.

### - This project and standardized tests have opened

doors for college, scholarships and more.

### - Understanding how to write and read technical documentation is key in a technical field like

computer science.

### - Communication skills taught in mission design have taught me effective public speaking and

team management.

### Morgan: - My leadership experience will has made me a prepared and experienced leader in not just general leadership settings but also in a virtual

settings.

### - ISS project and Youtube Platform have opened doors for college and special awards - Understanding how to plan and create content designed for a target audience to complete a certain objective is a skill I can apply to any

career path I choose to pursue in the future.

### - Communication skills taught in mission design have taught me effective public speaking and

team management.


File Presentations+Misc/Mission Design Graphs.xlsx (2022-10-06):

 | Pre-K | K | 1 | 2 | 3 | 4 | 5 | 6 | 7 | 8 | 9 | 10 | 11 | 12 | Adult
Male | 5.666666667 | 3 | 5 | 0 | 7.75 | 10 | 3.8333 | 7.625 | 7.285 | 6.666666666 | 6.666666667 | 8.68 | 9.095 | 5.833333333 | 9.58333333
Female | 0 | 5 | 4 | 3 | 8 | 7 | 5 | 6.666666667 | 7.307 | 7.846 | 7.23 | 7.428 | 7.307 | 6.75 | 7.310344828

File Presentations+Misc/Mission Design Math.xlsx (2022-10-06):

a=(PA/m)
43.68

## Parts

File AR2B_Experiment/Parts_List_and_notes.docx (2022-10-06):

Michael Blunt

ACED RED 2 B Parts List – High School Team Experiment

Abridged Parts List:

- SPS30
- HAT PCB (proprietary)
- M2.5 6mm Hex Standoffs (x4)
- M2.5 Nuts (x2)
- M2.5 6mm Screws (x2)
- M2.5 12mm Screws (x4)
- 5mm through-hole pi GPIO Header
- 5 pin connector (JST ZH 1.5)

SPS30 – Particulate Matter Sensor, main component of the experiment.

- Team modifications
  - Inside of the SPS30 is a small fan. We have disabled this fan following our given requirement of having no moving parts. After conducting tests with this fan disabled, we demonstrated that the SPS30 still functions accurately without the fan. This was seen best in our vacuum testing. All information and testing data/analysis has been communicated to UAH throughout the course of this project.
    - Disabling the fan – options:
      - Unplug it
        - While we are not electrical engineers, we consulted two electrical engineers about our problem citing concerns about power/load changes. They both said that simply “unplugging” or disconnecting the fan from the power source on the board should suffice. Currently, we have followed this method to disable the fan and noticed no negative effects in testing or otherwise.
      - Capacitors and Resistors
        - This solution is above our expertise and equipment level, but it was proposed nearly identically by both electrical engineers. They suggested connecting the power and control line to ground with a very tiny capacitor and a resistor. This implementation would have to be done by UAH or with UAH assistance, as we have neither the equipment, skills, or experience to attempt this. I hope this explanation makes sense, or at least provides a valuable idea.
  - The SPS30 came with a metal casing that can be removed to access the sensor internals. It appears to be a simple aluminum sheet held in by small clips.
    - The team was not satisfied that the original casing with solder anchors would hold the sensor in place.
    - I drilled holes through the plastic bottom of the SPS30 and added two screw/nut configurations to mount the sensor more securely to the HAT board.
      - UAH should not need to adjust this configuration as it passed all vibration testing, but it can be modified if needed. In other words, the mounting configuration does not affect the sensor function so long as the intake is not blocked.
    - On the bottom of the casing, 2 screws and 2 nuts hold the SPS30 onto the pi HAT.
- See the SPS30 folder for all manufacturer provided documents including:
  - Mechanical Design and Assembly
  - STEP file
  - Certificates
  - Sample Code
  - Other documents (flyers, compressed datasheet, etc.)

Pi HAT PCB – A very simple board, simply electrically connects the SPS30 to the pi. I jokingly say it is just a glorified wire.

- See attaching details for instructions on how to attach the HAT to a pi 3B+
- Attached should be a gerber file with the a printable HAT schematic.

Standoffs and Nuts – Exactly what they sound like, not much to them.

- Standoffs
  - M2.5
  - 6 millimeters.
  - Four, one in each corner.
  - The exact type does not matter, any M2.5 standoff that is 6mm should work well.
- “Nuts”
  - There are two nuts holding the SPS30 to the pi HAT PCB, and they were actually made from a standoff.
  - I did not have two M2.5 nuts, so I cut a standoff roughly in half and used the two halves as nuts.
    - Obviously, if this is not satisfactory, UAH can purchase two M2.5 nuts for less than a dollar at any hardware store.

Corner Screws – Screws in the corner of the pi HAT that hold the HAT to the pi and baseplate.

- M2.5
- 12 millimeters.
- Machine screws (flat head).
- Four, one in each corner.
- The exact type does not matter, any M2.5 screw longer than 10mm should work well.
  - The length of the screw depends on the needs of the AR2B mounting equipment.

SPS30 Mounting Screws

- M2.5
- 6 millimeters.
- Machine screws (flat head).
- Two, anchoring the SPS30 to the pi HAT PCB.
- The exact type does not matter, any M2.5 screw 4 to 6mm should work well.
  - These screws are not important to the experiment configuration, just are used to hold the SPS30 to the HAT PCB.

GPIO Header 2x20 Short Female Header

- Purchased from Adafruit.com, essentially raises our HAT 6mm off the surface of the pi PCB
  - 1mm GPIO base on 3B+.
  - 5mm pin height.
- Dimensions: 51mm x 8mm x 5mm / 2.0" x 0.3" x 0.2"
- Pin Length: 3mm
- Pin Spacing: 2.5mm / 0.1"
- Pin Thickness: 0.6mm / 0.02"
- Weight: 2g
- We soldered the pins on this short header to our HAT PCB.

5 pin connector - JST ZH 1.5 5 pin connector

- This is an unusual connector standard, and we had some difficulty finding preassembled wires for sale online.
- We were able to get a set of 10.
  - Blue – 5V Power
  - Green – SDA
  - Yellow – SCL
  - Red and Black – Ground
- The colors DO NOT correspond to their normal associations
  - RED IS NOT 5V
- Please take care not to accidentally “flip” or invert the 5 pin connector if resoldering is needed.
  - If resoldering is needed, please test all connections with a multimeter continuity check before proceeding.

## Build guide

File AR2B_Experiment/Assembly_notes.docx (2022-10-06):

Michael Blunt

Assembly Notes

This document is intended to assist when attaching the HAT and experiment to a raspberry pi 3B+ computer. The mechanical configuration of the experiment has been designed to be as simple as possible, and hopefully will not present a challenge to assemble.

Initial Setup:

- To assemble the experiment, you need:
  - HAT/experiment
  - M2.5 screws
    - Length determined by UAH, supplied screws are 12mm.
    - x4
  - M2.5 standoffs
    - 6mm
    - X4
  - Pi 3B+

To Assemble:

- Remove all corner screws and standoffs from the pi HAT.
- Extra Pins
  - On the 3B+, there is an extra 4 pins not attached to the 40-pin standard used by our design.
  - We designed a cutout for this, but it is not properly aligned.
  - You can remediate this by either:
    - Shortening the height of the four pins with a Dremel.
    - Widening the hole in the HAT PCB to allow room for pins
      - So long as no other components are hit (SPS30 and Header are closest) AR2B team can widen the slot with a Dremel or other tool.
      - There are no imbedded wires anywhere near that side of the PCB board.
    - Bending the pins out of the way.
      - In testing, we bent the pins out of the way away from each other.
      - Not an ideal configuration, but it was the best we could do.
      - This was definitely the sloppiest part of this entire project.
- Slide the HAT down onto the pi’s GPIO Header.
  - This is the most difficult part of the entire assembly.
  - Try to keep the HAT level with the pi and push down on the two corners adjacent to the GPIO header.
    - The idea is to provide uniform pressure to push the GPIO pins through the receiver on the HAT.
    - If the HAT is pushed onto the GPIO header at an angle, you may damage the experiment or the pi.
  - Push until no GPIO header is exposed below the surface of the HAT.
    - The black receiver should be pressed against the black GPIO base and no metal GPIO header should be visible.
  - Slide 6mm standoffs in between the pi and HAT.
    - May take some working, this is a very tight fit.
    - Repeat this step for all four corners.
  - Screw through standoffs.
    - Insert screws of desired length and screw through the standoffs into baseplate.
  - Insert SD card into SD card slot.

Congratulations, you have successfully assembled this experiment. When supplied with power, it should function properly.

- Testing proper functionality
  - First, simply leave the experiment plugged in for thirty minutes and watch for a restart.
    - If there are any program errors, the pi will restart itself to alleviate the issuu.
  - If the experiment passed this step, manually test for program functionality using the ps -aux with the grep command.
    - “ps -aux | grep startup”
    - “ps -aux | grep monitor”
    - “ps -aux | grep sps30”
    - “ps -aux | grep UAH”
    - “ps -aux | grep transfer”
      - All of these commands should return two results, or running processes.
        - One of the results is the search, the other is the program.

Congratulations, you have successfully assembled and tested this experiment. Thank you for setting it up!

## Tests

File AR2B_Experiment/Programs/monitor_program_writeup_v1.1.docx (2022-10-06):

AR2B Particulate Matter Experiment:

Monitor.sh

Monitor.sh waits 20 minutes to start, this allows a buffer time for programs to launch and will allow usable data to be collected if this program malfunctions (false positives).

Loop:

- The while loop encasing the program and the 10 minute buffer time should allow the program to continuously check for errors during operation time.

Variables:

- Logs: (identified and read via cat command)
  - Startup
  - Transfer
  - UAH
  - Sensor
- Time:
  - Initialized as a variable to compare with log times.
- Other Variables:
  - Results of string splitting from the log data, largely self explanatory.
    - Ex: startup_hour is the hour that the startup program was launched in.
    - Ex: transfer_minute is the minute that the transfer program was launched in.

Startup Checker:

Note: pseudocode does not follow any convention, simply is intended allow readers without an understanding of bash to read the code logic.

First if statement pseudocode:

- if started TODAY or YESTERDAY or TOMORROW return DATE_GOOD else DATE_BAD
- Pass example: (startup date = 1/1/22, current date = 1/2/22)
  - 1/1/22 == TODAY returns false
  - 1/1/22 == YESTERDAY returns true
  - 1/1/22 == TOMORROW returns false
    - Because these are all “or” statements, result is true
- Fail Example: (startup date = 1/1/22, current date = 1/3/22)
  - 1/1/22 == TODAY returns false
  - 1/1/22 == YESTERDAY returns false
  - 1/1/22 == TOMORROW returns false
    - This check theoretically should never trigger due to startup.sh’s inbuilt 12hr restart clock, but this check is here for redundancy.

Second If Statement:

- Checks the hour in which the program was launched
- Pseudocode:
  - if LAUNCH_HOUR == CURRENT_HOUR return TRUE else FALSE
    - True occurs when hours are the same (ex: 8 and 8) continues to the third if statement.
    - False occurs when hours are different and can only occur when the restart happened less than 12 hours ago. This should be the most common return.

Third If Statement:

- Checks to see if the hour is am or pm:
- Pseudocode:
  - if LAUNCH_AM_PM == CURRENT_AM_PM return TRUE else FALSE
  - Ex: (launch=pm, current = am)
    - if PM == AM return TRUE else FALSE
      - True only occurs when check is executed in the same hour as the launch (ex: launch = 8:00 am and check = 8:10)
      - False should be the check that fails at the 12 hour marker, and restarts the system. This should be restarting around the same time as startup.sh, so there is redundancy to this measure.

Transfer Check:

The transfer program is intended to execute in a loop every second to move programs from the /home/pi/ or /home/pi/Programs/ directories to /tmp/experiment/ for use by UAH’s program. After moving the files, transfer.sh writes the current time to its log file.

Transfer Pseudocode:

- if LOGGED_MINUTE (is within two minutes of) CURRENT_MINUTE return TRUE else FALSE
  - True means the program is looping properly, as the log file is within an acceptable deviation from the current time.
    - 2 minutes was chosen as it is the approximate time taken to launch the system and is not enough time to produce a harmful amount of data files.
  - False should/has never occur/ed, but in the event that it does this false will restart the system to handle this problem preventing massive amounts of packets from taking up storage space.

UAH and Sensor Check:

- Uses the exact same mechanics as the startup check, see above.

Notes and Warnings:

- DO NOT CHANGE SYSTEM TO A 24 HR CLOCK!!!!
  - This should be largely self-explanatory, but it will break many of the checks in this program. This program must be edited to work on a 24hr clock.

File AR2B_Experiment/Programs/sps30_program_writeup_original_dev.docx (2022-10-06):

# Raspi-Driver-SPS30

Software to read out [Sensirion SPS30](https://www.sensirion.com/en/environmental-sensors/particulate-matter-sensors-pm25/) PM sensor values over I2C on Raspberry Pi.

This software is licenced under GPLv3 by [UnravelTEC OG](https://unraveltec.com) (https://unraveltec.com), 2018.

## Prerequisites

Maximum I2C speed for SPS30 is 100kHz (Default on Raspbian).

Recommended maximum I2C cable length 20cm.

Sensor needs 5V, on I2C bus 3.3V is fine. Seems to work without external pull-ups on Raspberry Pi 3B+ on i2c-1.

### Pigpiod & Python

As the SPS30 needs complex i2c-commands, the Linux standard i2c-dev doesn't work. A working alternative is pigpiod (we are using it through python).

```

aptitude install pigpio python3-crcmod python3-pigpio i2c-tools

```

Atm, IPv6 doesn't work on Raspbian correctly with pigpiod, so:

```

sed -i "s|^ExecStart=.*|ExecStart=/usr/bin/pigpiod -l -n 127.0.0.1|" /lib/systemd/system/pigpiod.service

systemctl restart pigpiod

# Test (should return an int)

pigs hwver

```

## Run program

```

python sps30-service.py

```

## Installation

To install it as a background service run ./install.sh (install dependencies, e.g. via apt, first).

This service writes a file - suited for scraping by prometheus - (onto ramdisk on /run/sensors/sps30/last) and updates it every second.

# Notes

## Stability

When running on a RPi 0W powered by a USB3.0 PC port, (4.8V resulting), the sensor stops reliably working after 60s, and has to be resettet. Use a proper PSU.

## Data credibility

data values in the first 15 seconds while the fan is spinning up are too high, recommended to ignore them.

## Calculation of pm values

The pm* values (µg/m³) are summed up - pm10 is every particle <10µm, pm4 is every particle <4µm, etc. If e.g. there are no particles > 2.5µm, pm2.5 - pm10 are the same.

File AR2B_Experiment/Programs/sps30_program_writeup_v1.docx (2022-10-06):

Michael Blunt

sps30 writeup

This is a complex python program that utilizes many advanced packages, functions, and communications. However, the function names in conjunction with the comments throughout added by myself and the original devs (UnravelTEC) are very helpful. I will not provide a specific line by line analysis of the code, rather, I will provide a general overview of functionality and intended purpose.

Initial Setup:

- The program starts by defining variables and basic functions.
  - “eprint” is a custom function for printing error messages
  - pigpio and I2C static variables are set
- I2C detect is called and run
  - If SPS30 is found, returns 0
  - Else exit(1)
- Exit gracefully
  - This function is never used in our program, as the SPS30 program should never have to terminate itself.

PigPio:

- This is more into the realm of UnravelTEC’s work, I did not write or edit much of this at all. No documentation on these specific functions is available (see their writeup) so I will do my best to interpret.
- Starts by checking if pigpio daemon is running on localhost
  - If not prints an error message
- Closes the previous “checking” connection
  - Checks and handles error to this function
- Opens a connection and assigns it to variable “h”
  - Lots of commented functions here, I believe I received this code with these functions commented out.

Communication and Data Gathering:

- This is also entirely UnravelTEC’s work, but I will document it as well as I can. Everything is defined as a function and called later on in the program.
- Read Bytes:
  - Attempts to read bytes from I2C connection
- Write Bytes:
  - Attempts to write bytes to I2C connection, returns true if you can write to the I2C connection
- Read From Address:
  - Not sure the specifics of this function, appears to attempt to read from a range of addresses 3 separate times.
- Read Article Code:
  - Reads the article code from SPS30 from specific address and prints it
- Read Serial Number
  - Reads the serial number from SPS30 from specific address and prints it
- Read Cleaning Interval
  - Reads the cleaning interval and prints it

Measurements:

- Start/stop measurement
  - Self explanatory, resets SPS30 if error is thrown
- Reset
  - Tries a “nice” reset, sends reset request to SPS30
- Data ready
  - Throws errors if data is wrong or did not return anything
- Calculate Integer/Float
  - No idea what is happening in the internals but it returns a variable apiece that is used later in outputs
- Print Prometheus
  - Returns data to a log file
- Print Human
  - Prints a human readable version of the data
- Read PM Values
  - Reads values from specified addresses, passes data to the Prometheus and Human (if DEBUG=true) functions
- Initialize
  - starts the measurements or exists if false
- Big Reset
  - Resets and closes the pigpio connection

Team Function (run):

- This is the section of code most modified
- Steps:
  - Makes log file
  - Resets
  - Initialize
  - Checks to make sure data is available
  - Calculates the data manually,
    - Borrowed method from printHuman
  - Creates a json formatted file
  - Defines filename as the current UNIX timestamp
  - Places files in /home/pi/
  - Takes timestamp from transfer_log.txt
    - Writes that into its own log (sensor_log.txt)

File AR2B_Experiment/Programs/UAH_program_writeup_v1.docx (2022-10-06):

Michael Blunt

UAH Starter writeup

A very simple program, it honestly does not even need a writeup.

Line by line analysis:

- Writes the current time into a file named UAH_starter_log.txt
- Starts the UAH transfer program
  - Comment out “—no-connect” for the program to work properly

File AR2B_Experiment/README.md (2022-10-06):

### AR2B Experiment

This is my attempt to gather everything from this project in one central and easily accesible location.

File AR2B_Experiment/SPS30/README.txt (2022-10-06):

Everything in this folder was pulled directly from the Sensirion website. I am not sure what will be needed and no longer available online in the future. 

-Michael Blunt

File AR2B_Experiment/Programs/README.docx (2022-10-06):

Michael Blunt

Experiment Programs – Notes and Important Information

Setup Notes:

- Included with the experiment is an SD card with a fully functional system.
  - All that is needed is to simply insert this SD card into the new pi.
- You should not need to manually install the programs onto a new OS.
- We have provided an SD card with a copy of our entire operating system, complete with system settings, crontabs, and programs installed and working (1/19/2022).
  - Michael Blunt will retain an additional copy of this operating system, in the event of damage to the copy.
  - If you wish to make an additional copy from the SD card supplied with the experiment, go to the raspberrian desktop, and select the SD copier utility.
    - If you receive size errors, optimize the size of the original SD card by freeing up space.
    - Alternatively, use third party software to turn the system into a “.img” file and proceed from there.

Users and Root:

- There are two users on the system, “pi” and “root”
  - “pi” is an administrator and can execute the sudo command with no password.
    - user:pass is pi:detects
  - “root” is the inbuilt system administrator and is the equivalent of a Windows sysadmin.
    - user:pass is root:detects
  - All passwords can be found in a file called “the_password” on the Desktop.
  - If all else fails, there is an SUID binary in the under the “Random_Programs” directory in the “/home/pi/Programs” directory.
    - You should be able to use this program to execute commands with root privileges without a password.
- Security Note:
  - This system was NOT made with security in mind.
    - There are intentional security holes, weak passwords, etc.
  - THIS SYSTEM SHOULD NOT BE EXPOSED TO ANY UNTRUSTED SOURCE.
    - This system was intentionally designed to allow anyone with physical access to gain administrator privileges relatively easily.
    - PLEASE SECURE THIS MACHINE FROM ANY UNTRUSTED USERS.

In Case of Problems with SD card:

- If none of the above items can solve the problem associated with the programs or SD card, please contact Michael Blunt (see misc. notes).
- Worst case scenario:
  - In the highly unlikely event of a non-response, there are two main system configurations not explicitly shown in this folder that need to be configured for the experiment to work properly.
    - Crontab
      - There is one crontab command that launches startup.sh in the background. This works best with a thirty second delay from initial crontab run.
    - BIOS Settings
      - Needs to be configured to detect I2C devices. Should be accessible via the BIOS menu under option number five.

Miscellaneous Notes:

- Michael Blunt handled all software, please direct any questions to michaelbblunt@gmail.com or 8437099457.

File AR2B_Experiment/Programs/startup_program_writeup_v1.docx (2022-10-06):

Michael Blunt

Startup.sh writeup

Startup.sh is intended to be a vessel for launching all required programs and starting a restart clock. Before this project, I did not know how to use crontabs to launch programs, so for my simplicity and understanding, I only launched one program. This program is not strictly necessary for the program design, but honestly it is less complex to edit than a crontab anyways, so I prefer this method. Here is the basic flow of this our startup sequence.

(System booting up) → root crontab (/etc/crontab) → startup.sh → everything else

Line by Line explanation:

- Changes directories to /home/pi/Programs, not required since we are using absolute paths
  - Obsolete feature left over from the first versions of this program. I have since learned how about absolute versus relative paths, which is a much more reliable method that is not reliant on the user that runs the program.
  - Non-technical explanation:
    - Obsolete feature, it has no impact on current functionality.
    - Was used to specify the “working directory” or the area in which the program ran.
    - Has been replaced by using absolute paths, or using the full system path of a folder from the root directory to execute a program, create a file, etc.
- Launches programs:
  - IMPORTANT: the ampersand after launch commands specifies the programs are to be backgrounded, this is what allows startup.sh to launch multiple programs and not be stuck after launching the first program. DO NOT REMOVE THE AMPERSANDS!
  - Transfer
    - Shellscript, launched with “sh” command
  - Monitor
    - Shellscript, launched with “sh” command
  - Sensor
    - Python program, runs on python3
  - UAH
    - Shellscript, launched with “sh” command
  - Note: any of the programs can be disabled at next reboot by “commenting” them out with a pound character in front of the line (“#”)
- Log:
  - After the programs are launched, the startup.sh program writes to a log file with the current time. This occurs before the restart clock is started, so if the clock fails to start for some unknown reason, no error will be thrown. I am aware of this possibility and have added a failsafe in the monitor program (see startup check writeup in monitor program writeup).
- Restart timer:
  - Very simple, sleeps for 720 minutes (12 hours) and then triggers a restart.

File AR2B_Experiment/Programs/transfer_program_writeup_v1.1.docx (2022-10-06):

Michael Blunt

Transfer.sh writeup

The transfer program is intended to transfer files out of the /home/pi/ and /home/pi/Programs/ directories and into the /tmp/experiment/ directory. This is a very simple program with a very important purpose. If to many files are stored in the /home/pi/ and /home/pi/Programs/ directories then the system will run out of storage.

Line by Line analysis:

Mkdir:

- This line creates the /tmp/experiment/ directory. It will return a warning if it already exists, but this can be ignored.

While loop:

- The loop should always return true, as variable a (which equals 0) should always be less than 100.
  - Can be simplified to “while TRUE”
- The transfer program moves the files without alteration from the /home/pi/ and /home/pi/Programs/ directories into the /tmp/experiment/ directory.
- It then writes the current time to its log file, and pauses for one second before restarting the loop.
- This program should never exit, as the a value should never increment.

This is a very simple little program. It should not be a source of troubles.

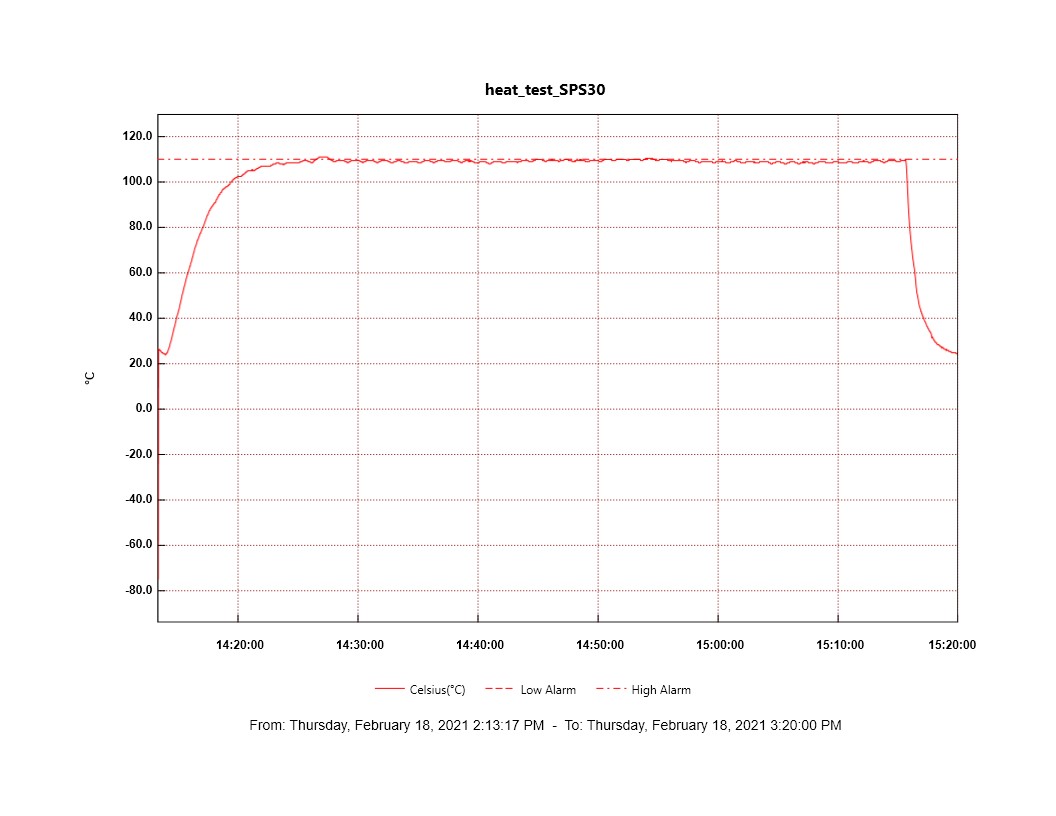
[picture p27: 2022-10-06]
Pictures/heat_test_SPS30.jpg

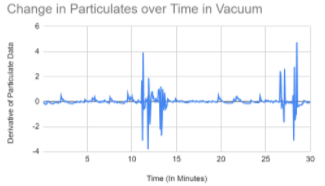
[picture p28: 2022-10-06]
Pictures/VacuumTestGraph.PNG

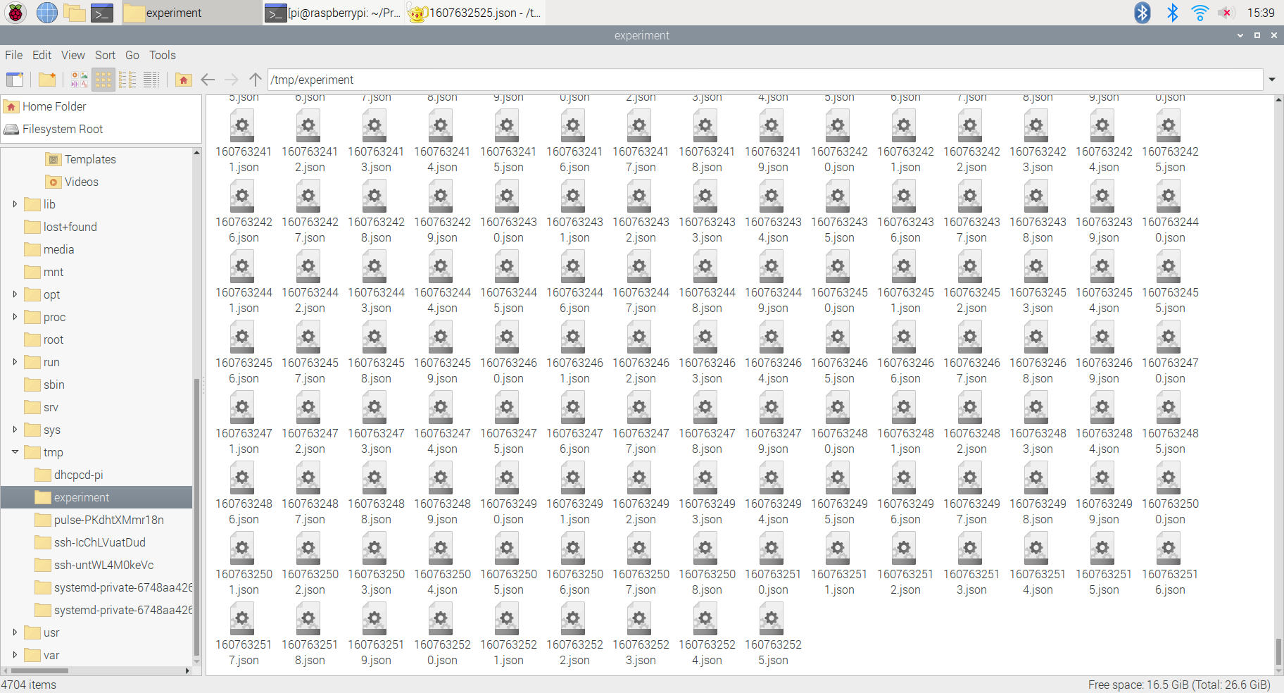
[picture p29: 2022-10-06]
Pictures/populated_tmp_experiment2.png

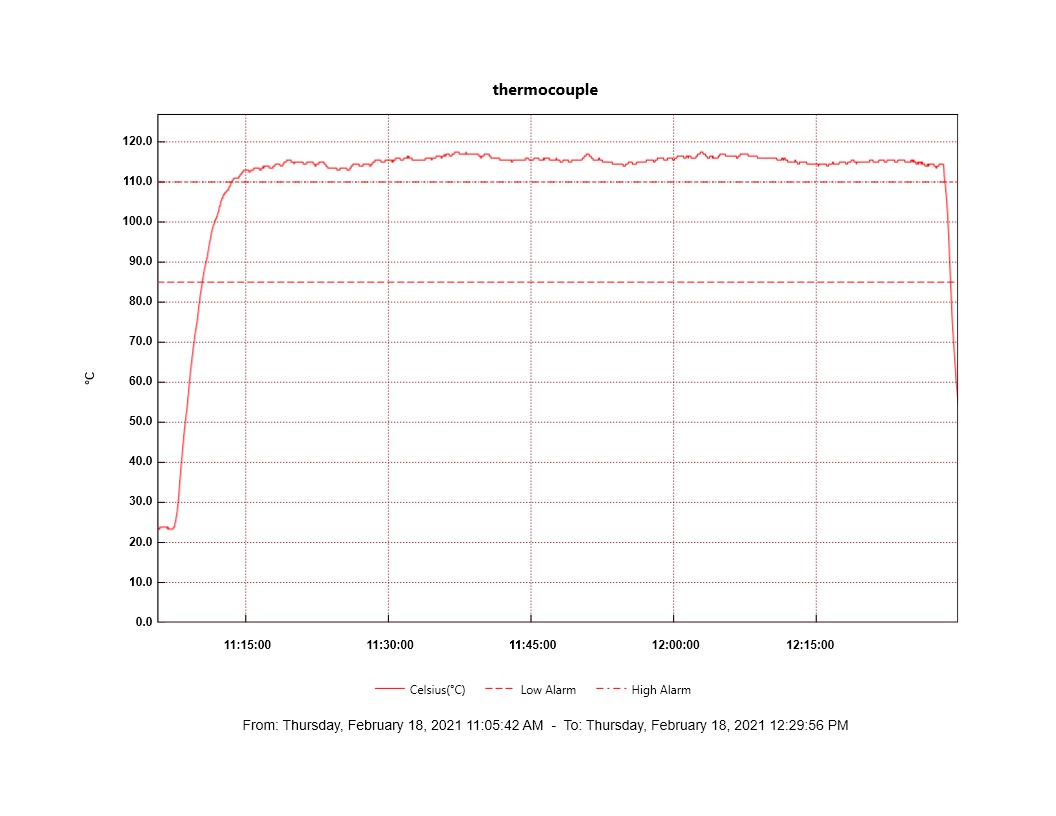
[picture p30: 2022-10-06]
Pictures/heat_test_PCB_board.jpg

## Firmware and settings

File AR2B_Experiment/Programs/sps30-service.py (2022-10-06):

#!/usr/bin/env python3
# coding=utf-8
#
# Edited for UAH's ARB2 Mission by Michael Blunt
#
# This program must be run from the ~/Programs folder if started manually for log functionality to work.
import pigpio # apt install python3-pigpio, used for I2C communications. Not the library UAH suggested, we used this as it offers greater functionality and flexibility. 
import time
import struct
import sys
import crcmod # apt install python3-crcmod
import os, signal
import subprocess
from subprocess import call
import json
import pprint

#define error print (eprint) to print errors from stderr
def eprint(*args, **kwargs):
  print(*args, file=sys.stderr, **kwargs)

#there is a logfile not in /tmp/, it should not generate enough packets to be problematic
LOGFILE = '/run/sensors/sps30/last'

PIGPIO_HOST = '127.0.0.1'
I2C_SLAVE = 0x69
I2C_BUS = 1

DEBUG = False

deviceOnI2C = call("i2cdetect -y 1 0x69 0x69|grep '\--' -q", shell=True) # grep exits 0 if match found
if deviceOnI2C:
  print("I2Cdetect found SPS30")
else:
  print("SPS30 (0x69) not found on I2C bus") #happens in testing when SPS30 is not connected properly
  exit(1)

def exit_gracefully(a,b): # never is triggered by our program
  print("exit")
  stopMeasurement()
  os.path.isfile(LOGFILE) and os.access(LOGFILE, os.W_OK) and os.remove(LOGFILE)
  pi.i2c_close(h)
  exit(0)

signal.signal(signal.SIGINT, exit_gracefully)
signal.signal(signal.SIGTERM, exit_gracefully)


#pigpio stuff, we initialized the I2C stuff above now we actually initiate a connection

pi = pigpio.pi(PIGPIO_HOST) #checks daemon running on localhost
if not pi.connected:
  eprint("no connection to pigpio daemon at " + PIGPIO_HOST + ".")
  exit(1)
else:
  if DEBUG:
    print("connection to pigpio daemon successful")


try:
  pi.i2c_close(0)
except:
  tupl = sys.exc_info()
  if tupl[1] and str(tupl[1]) != "'unknown handle'":
    eprint("Unknown error: ", tupl)

#try:
h = pi.i2c_open(I2C_BUS, I2C_SLAVE)
#except:
#  eprint("i2c open failed")
#  exit(1)

#def i2cOpen(): #commented out by 
#  global h
#  try:
#    h = pi.i2c_open(I2C_BUS, I2C_SLAVE)
#  except:
#    eprint("i2c open failed")
#    exit(1)


f_crc8 = crcmod.mkCrcFun(0x131, 0xFF, False, 0x00)

def calcCRC(TwoBdataArray):
  byteData = ''.join(chr(x) for x in TwoBdataArray)
  return f_crc8(byteData.encode())

# print(hex(calcCRC([0xBE,0xEF])))

def readNBytes(n):
  try:
    (count, data) = pi.i2c_read_device(h, n)
  except:
    eprint("error: i2c_read failed")
    exit(1)

  if count == n:
    return data
  else:
    eprint("error: read bytes didnt return " + str(n) + "B")
    return False

# takes an array of bytes (integer-array)
def i2cWrite(data):
  try:
    pi.i2c_write_device(h, data)
  except Exception as e:
    pprint.pprint(e)
    eprint("error in i2c_write:", e.__doc__ + ":",  e.value)
    return -1
  return True

def readFromAddr(LowB,HighB,nBytes):
  for amount_tries in range(3):
    ret = i2cWrite([LowB, HighB])
    if ret != True:
      eprint("readFromAddr: write try unsuccessful, next")
      continue
    data = readNBytes(nBytes)
    if data:
      return data
    eprint("error in readFromAddr: " + hex(LowB) + hex(HighB) + " " + str(nBytes) + "B did return Nothing")
  eprint("readFromAddr: write tries(3) exceeded")
  return False

def readArticleCode():
  data = readFromAddr(0xD0,0x25,47)
  if data == False:
    eprint('readArticleCode failed')
    return False

  acode = ''
  crcs = ''
  for i in range(47):
    currentByte = data[i]
    if currentByte == 0:
      break;
    if (i % 3) != 2:
      acode += chr(currentByte) + '|'
    else:
      crcs += str(currentByte) + '.'
  print('Article code: "' + acode + '"')
  return True

def readSerialNr():
  data = readFromAddr(0xD0,0x33,47)
  if data == False:
    eprint('readSerialNr failed')
    return False

  snr = ''
  for i in range(47):
    if (i % 3) != 2:
      currentByte = data[i]
      if currentByte == 0:
        break;
      if i != 0:
        snr += '-'
      snr += chr(currentByte)
  print('Serial number: ' + snr)
  return True

def readCleaningInterval():
  data = readFromAddr(0x80,0x04,6)
  if data and len(data):
    interval = calcInteger(data)
    print('cleaning interval:', str(interval), 's')

def startMeasurement():
  ret = -1
  for i in range(3):
    ret = i2cWrite([0x00, 0x10, 0x03, 0x00, calcCRC([0x03,0x00])])
    if ret == True:
      return True
    eprint('startMeasurement unsuccessful, next try')
    bigReset()
  eprint('startMeasurement unsuccessful, giving up')
  return False

def stopMeasurement():
  i2cWrite([0x01, 0x04])

def reset():
  if DEBUG:
    print("reset called")
  for i in range(5):
    ret = i2cWrite([0xd3, 0x04])
    if DEBUG:
      print("reset sent")
    if ret == True:
      if DEBUG:
        print("reset ok")
      return True
    eprint('reset unsuccessful, next try in', str(0.2 * i) + 's')
    time.sleep(0.2 * i)
  eprint('reset unsuccessful')
  return False



def readDataReady():
  data = readFromAddr(0x02, 0x02,3)
  if data == False:
    eprint("readDataReady: command unsuccessful")
    return -1
  if data and data[1]:
    if DEBUG:
      print("âœ“")
    return 1
  else:
    if DEBUG:
      print('.',end='')
    return 0

def calcInteger(sixBArray):
  integer = sixBArray[4] + (sixBArray[3] << 8) + (sixBArray[1] << 16) + (sixBArray[0] << 24)
  return integer

def calcFloat(sixBArray):
  struct_float = struct.pack('>BBBB', sixBArray[0], sixBArray[1], sixBArray[3], sixBArray[4])
  float_values = struct.unpack('>f', struct_float)
  first = float_values[0]
  return first

def printPrometheus(data):
  pm10 = calcFloat(data[18:24])
  if pm10 == 0:
    eprint("pm10 == 0; ignoring values")
    return

  output_string = 'particulate_matter_ppcm3{{size="pm0.5",sensor="SPS30"}} {0:.8f}\n'.format( calcFloat(data[24:30]))
  output_string += 'particulate_matter_ppcm3{{size="pm1",sensor="SPS30"}} {0:.8f}\n'.format( calcFloat(data[30:36]))
  output_string += 'particulate_matter_ppcm3{{size="pm2.5",sensor="SPS30"}} {0:.8f}\n'.format( calcFloat(data[36:42]))
  output_string += 'particulate_matter_ppcm3{{size="pm4",sensor="SPS30"}} {0:.8f}\n'.format( calcFloat(data[42:48]))
  output_string += 'particulate_matter_ppcm3{{size="pm10",sensor="SPS30"}} {0:.8f}\n'.format( calcFloat(data[48:54]))
  output_string += 'particulate_matter_ugpm3{{size="pm1",sensor="SPS30"}} {0:.8f}\n'.format( calcFloat(data))
  output_string += 'particulate_matter_ugpm3{{size="pm2.5",sensor="SPS30"}} {0:.8f}\n'.format( calcFloat(data[6:12]))
  output_string += 'particulate_matter_ugpm3{{size="pm4",sensor="SPS30"}} {0:.8f}\n'.format( calcFloat(data[12:18]))
  output_string += 'particulate_matter_ugpm3{{size="pm10",sensor="SPS30"}} {0:.8f}\n'.format( pm10 )
  output_string += 'particulate_matter_typpartsize_um{{sensor="SPS30"}} {0:.8f}\n'.format( calcFloat(data[54:60]))
  # print(output_string)
  logfilehandle = open(LOGFILE, "w",1)
  logfilehandle.write(output_string)
  logfilehandle.close()
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
